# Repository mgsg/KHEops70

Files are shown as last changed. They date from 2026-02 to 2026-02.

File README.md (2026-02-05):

# KHEops70 
Keyboard | Hall Effect | OrthoLinear | Programmable | Standard-sized

| WARNING: DIY project. Use at your own risk!

| Forked from the [Moonboard Keyboard](https://github.com/certainly1182/MoonBoard).

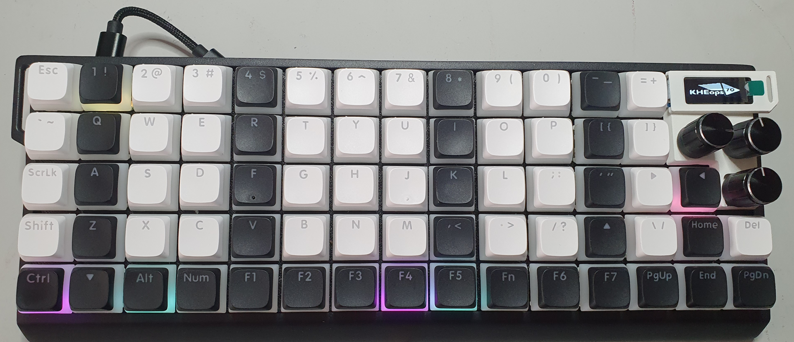
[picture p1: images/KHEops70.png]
KHEops70
<p>&nbsp;&nbsp;&nbsp;&nbsp;&nbsp;&nbsp;&nbsp;&nbsp;</p>

## Features

- 70 HE switches, 60% case, 13x5 + 5 keys + 1 encoder + 2 potentiometers in ortholinear arrangement.
- All keys are 1u. Keycaps in uniform profile preferred (XDA, DSA...).
- QMK Firmware compatibility.
- QMK MIDI Support (Audio support buggy).
- Compatibility with "standard" widely available 60% keyboard cases.
- OLED display.

## Hardware

Design for PCBs can be found in the hardware folder.

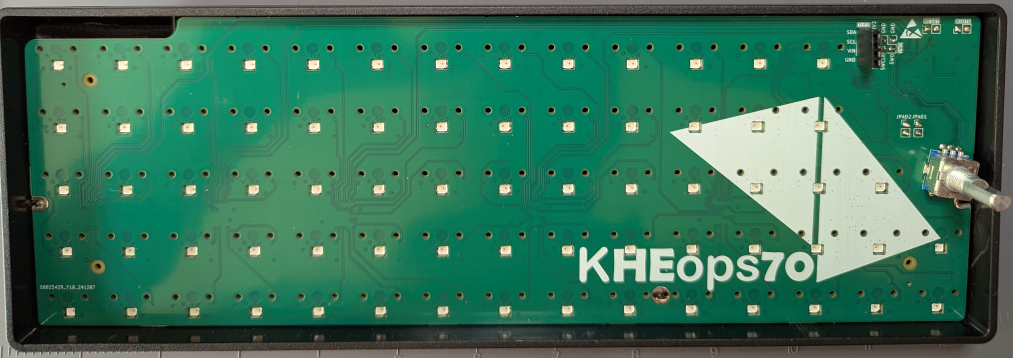
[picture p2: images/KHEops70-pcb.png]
KHEops70
<p>&nbsp;&nbsp;&nbsp;&nbsp;&nbsp;&nbsp;&nbsp;&nbsp;</p>

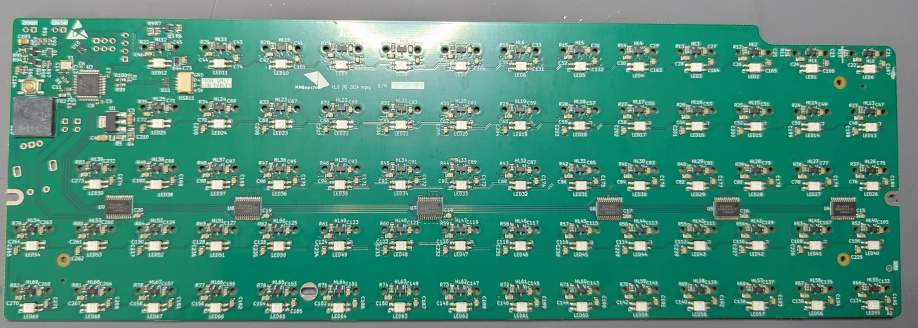
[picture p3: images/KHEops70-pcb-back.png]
KHEops70
<p>&nbsp;&nbsp;&nbsp;&nbsp;&nbsp;&nbsp;&nbsp;&nbsp;</p>

## Firmware

Compiled firmware provided as is. Largely based on the [Moonboard firmware found here](https://github.com/RephlexZero/qmk_firmware/tree/adc_testing/keyboards/rephlex/moonboard). Modified keyboard.json provided.

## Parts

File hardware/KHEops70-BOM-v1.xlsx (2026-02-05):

Comment | Designator | Footprint | JLCPCB Part #（optional）
r95 | BZ1 | Buzzer_Beeper:Buzzer_Murata_PKLCS1212E
PAD 1 Header | JPAD1 | Connector_PinHeader_2.54mm:PinHeader_1x02_P2.54mm_Vertical
PAD 2 Header | JPAD2 | Connector_PinHeader_2.54mm:PinHeader_1x02_P2.54mm_Vertical
RGB_DATA_OUT | TP1 | TestPoint:TestPoint_Pad_D1.5mm
STM32F303CBTx | U3 | Package_QFP:LQFP-48_7x7mm_P0.5mm | C108516
10u | C3 | Capacitor_SMD:C_1206_3216Metric | C13585
10u | C183 | Capacitor_SMD:C_1206_3216Metric | C13585
100u | C4 | Capacitor_SMD:C_1206_3216Metric | C15008
100n | C6 | Capacitor_SMD:C_0402_1005Metric | C1525
100n | C7 | Capacitor_SMD:C_0402_1005Metric | C1525
100n | C8 | Capacitor_SMD:C_0402_1005Metric | C1525
100n | C9 | Capacitor_SMD:C_0402_1005Metric | C1525
SM04B-SRSS-TB | USB11 | Connector_JST:JST_SH_SM04B-SRSS-TB_1x04-1MP_P1.00mm_Horizontal | C160404
10k | R93 | Resistor_SMD:R_0603_1608Metric | C17414
10k | R98 | Resistor_SMD:R_0603_1608Metric | C17414
10k | R6 | Resistor_SMD:R_0805_2012Metric | C17414
10k | R10 | Resistor_SMD:R_0805_2012Metric | C17414
10k | R11 | Resistor_SMD:R_0805_2012Metric | C17414
10k | R12 | Resistor_SMD:R_0805_2012Metric | C17414
10k | R13 | Resistor_SMD:R_0805_2012Metric | C17414
10k | R14 | Resistor_SMD:R_0805_2012Metric | C17414
10k | R15 | Resistor_SMD:R_0805_2012Metric | C17414
10k | R16 | Resistor_SMD:R_0805_2012Metric | C17414
10k | R17 | Resistor_SMD:R_0805_2012Metric | C17414
10k | R18 | Resistor_SMD:R_0805_2012Metric | C17414
10k | R19 | Resistor_SMD:R_0805_2012Metric | C17414
10k | R20 | Resistor_SMD:R_0805_2012Metric | C17414
10k | R21 | Resistor_SMD:R_0805_2012Metric | C17414
10k | R22 | Resistor_SMD:R_0805_2012Metric | C17414
10k | R23 | Resistor_SMD:R_0805_2012Metric | C17414
10k | R24 | Resistor_SMD:R_0805_2012Metric | C17414
10k | R25 | Resistor_SMD:R_0805_2012Metric | C17414
10k | R26 | Resistor_SMD:R_0805_2012Metric | C17414
10k | R27 | Resistor_SMD:R_0805_2012Metric | C17414
10k | R28 | Resistor_SMD:R_0805_2012Metric | C17414
10k | R29 | Resistor_SMD:R_0805_2012Metric | C17414
10k | R30 | Resistor_SMD:R_0805_2012Metric | C17414
10k | R31 | Resistor_SMD:R_0805_2012Metric | C17414
10k | R32 | Resistor_SMD:R_0805_2012Metric | C17414
10k | R33 | Resistor_SMD:R_0805_2012Metric | C17414
10k | R34 | Resistor_SMD:R_0805_2012Metric | C17414
10k | R35 | Resistor_SMD:R_0805_2012Metric | C17414
10k | R37 | Resistor_SMD:R_0805_2012Metric | C17414
10k | R38 | Resistor_SMD:R_0805_2012Metric | C17414
10k | R39 | Resistor_SMD:R_0805_2012Metric | C17414
10k | R40 | Resistor_SMD:R_0805_2012Metric | C17414
10k | R41 | Resistor_SMD:R_0805_2012Metric | C17414
10k | R42 | Resistor_SMD:R_0805_2012Metric | C17414
10k | R43 | Resistor_SMD:R_0805_2012Metric | C17414
10k | R44 | Resistor_SMD:R_0805_2012Metric | C17414
10k | R45 | Resistor_SMD:R_0805_2012Metric | C17414
10k | R46 | Resistor_SMD:R_0805_2012Metric | C17414
10k | R47 | Resistor_SMD:R_0805_2012Metric | C17414
10k | R48 | Resistor_SMD:R_0805_2012Metric | C17414
10k | R49 | Resistor_SMD:R_0805_2012Metric | C17414
10k | R52 | Resistor_SMD:R_0805_2012Metric | C17414
10k | R53 | Resistor_SMD:R_0805_2012Metric | C17414
10k | R54 | Resistor_SMD:R_0805_2012Metric | C17414
10k | R55 | Resistor_SMD:R_0805_2012Metric | C17414
10k | R56 | Resistor_SMD:R_0805_2012Metric | C17414
10k | R57 | Resistor_SMD:R_0805_2012Metric | C17414
10k | R58 | Resistor_SMD:R_0805_2012Metric | C17414
10k | R59 | Resistor_SMD:R_0805_2012Metric | C17414
10k | R60 | Resistor_SMD:R_0805_2012Metric | C17414
10k | R61 | Resistor_SMD:R_0805_2012Metric | C17414
10k | R62 | Resistor_SMD:R_0805_2012Metric | C17414
10k | R63 | Resistor_SMD:R_0805_2012Metric | C17414
10k | R64 | Resistor_SMD:R_0805_2012Metric | C17414
10k | R66 | Resistor_SMD:R_0805_2012Metric | C17414
10k | R67 | Resistor_SMD:R_0805_2012Metric | C17414
10k | R68 | Resistor_SMD:R_0805_2012Metric | C17414
10k | R69 | Resistor_SMD:R_0805_2012Metric | C17414
10k | R70 | Resistor_SMD:R_0805_2012Metric | C17414
10k | R71 | Resistor_SMD:R_0805_2012Metric | C17414
10k | R72 | Resistor_SMD:R_0805_2012Metric | C17414
10k | R73 | Resistor_SMD:R_0805_2012Metric | C17414
10k | R74 | Resistor_SMD:R_0805_2012Metric | C17414
10k | R75 | Resistor_SMD:R_0805_2012Metric | C17414
10k | R76 | Resistor_SMD:R_0805_2012Metric | C17414
10k | R77 | Resistor_SMD:R_0805_2012Metric | C17414
10k | R78 | Resistor_SMD:R_0805_2012Metric | C17414
10k | R79 | Resistor_SMD:R_0805_2012Metric | C17414
10k | R80 | Resistor_SMD:R_0805_2012Metric | C17414
10k | R81 | Resistor_SMD:R_0805_2012Metric | C17414
10k | R82 | Resistor_SMD:R_0805_2012Metric | C17414
10k | R83 | Resistor_SMD:R_0805_2012Metric | C17414
10k | R94 | Resistor_SMD:R_0805_2012Metric | C17414
1k | R7 | Resistor_SMD:R_0805_2012Metric | C17513
1 | R4 | Resistor_SMD:R_1206_3216Metric | C17928
1 | R5 | Resistor_SMD:R_1206_3216Metric | C17928
74HC4067 | U4 | Package_SO:TSSOP-24_4.4x7.8mm_P0.65mm | C179326
74HC4067 | U5 | Package_SO:TSSOP-24_4.4x7.8mm_P0.65mm | C179326
74HC4067 | U6 | Package_SO:TSSOP-24_4.4x7.8mm_P0.65mm | C179326
74HC4067 | U7 | Package_SO:TSSOP-24_4.4x7.8mm_P0.65mm | C179326
74HC4067 | U8 | Package_SO:TSSOP-24_4.4x7.8mm_P0.65mm | C179326
74HC4067 | U9 | Package_SO:TSSOP-24_4.4x7.8mm_P0.65mm | C179326
H5VU25U | U10 | MoonBoard:DFN2510 | C20615800
H5VU25U | U11 | MoonBoard:DFN2510 | C20615800
0 | R8 | Resistor_SMD:R_0603_1608Metric_Pad0.98x0.95mm_HandSolder | C21189
0 | R99 | Resistor_SMD:R_0603_1608Metric_Pad0.98x0.95mm_HandSolder | C21189
0 | R100 | Resistor_SMD:R_0603_1608Metric_Pad0.98x0.95mm_HandSolder | C21189
1k | R97 | Resistor_SMD:R_0603_1608Metric | C21190
1N4148WS | D1 | Diode_SMD:D_SOD-323 | C2128
1N4148WS | D44 | Diode_SMD:D_SOD-323 | C2128
1M | R92 | Resistor_SMD:R_0603_1608Metric | C22935
330k | R91 | Resistor_SMD:R_0603_1608Metric | C23137
4u7 | C5 | Capacitor_SMD:C_0402_1005Metric | C23733
100 | R96 | Resistor_SMD:R_0805_2012Metric | C25076
470R | R2 | Resistor_SMD:R_0805_2012Metric | C25117
470 | R9 | Resistor_SMD:R_0805_2012Metric | C25117
100k | R95 | Resistor_SMD:R_0805_2012Metric | C25741
1k5 | R1 | Resistor_SMD:R_0805_2012Metric | C25867
SW_SPST | SW1 | Button_Switch_SMD:SW_SPST_TL3342 | C2886897
SLSS49E-3 | HL0 | MoonBoard:SLSS49E-3 with MX holes | C2904393
SLSS49E-3 | HL1 | MoonBoard:SLSS49E-3 with MX holes | C2904393
SLSS49E-3 | HL2 | MoonBoard:SLSS49E-3 with MX holes | C2904393
SLSS49E-3 | HL3 | MoonBoard:SLSS49E-3 with MX holes | C2904393
SLSS49E-3 | HL4 | MoonBoard:SLSS49E-3 with MX holes | C2904393
SLSS49E-3 | HL5 | MoonBoard:SLSS49E-3 with MX holes | C2904393
SLSS49E-3 | HL6 | MoonBoard:SLSS49E-3 with MX holes | C2904393
SLSS49E-3 | HL7 | MoonBoard:SLSS49E-3 with MX holes | C2904393
SLSS49E-3 | HL8 | MoonBoard:SLSS49E-3 with MX holes | C2904393
SLSS49E-3 | HL9 | MoonBoard:SLSS49E-3 with MX holes | C2904393
SLSS49E-3 | HL10 | MoonBoard:SLSS49E-3 with MX holes | C2904393
SLSS49E-3 | HL11 | MoonBoard:SLSS49E-3 with MX holes | C2904393
SLSS49E-3 | HL12 | MoonBoard:SLSS49E-3 with MX holes | C2904393
SLSS49E-3 | HL13 | MoonBoard:SLSS49E-3 with MX holes | C2904393
SLSS49E-3 | HL14 | MoonBoard:SLSS49E-3 with MX holes | C2904393
SLSS49E-3 | HL15 | MoonBoard:SLSS49E-3 with MX holes | C2904393
SLSS49E-3 | HL16 | MoonBoard:SLSS49E-3 with MX holes | C2904393
SLSS49E-3 | HL17 | MoonBoard:SLSS49E-3 with MX holes | C2904393
SLSS49E-3 | HL18 | MoonBoard:SLSS49E-3 with MX holes | C2904393
SLSS49E-3 | HL19 | MoonBoard:SLSS49E-3 with MX holes | C2904393
SLSS49E-3 | HL20 | MoonBoard:SLSS49E-3 with MX holes | C2904393
SLSS49E-3 | HL21 | MoonBoard:SLSS49E-3 with MX holes | C2904393
SLSS49E-3 | HL22 | MoonBoard:SLSS49E-3 with MX holes | C2904393
SLSS49E-3 | HL23 | MoonBoard:SLSS49E-3 with MX holes | C2904393
SLSS49E-3 | HL24 | MoonBoard:SLSS49E-3 with MX holes | C2904393
SLSS49E-3 | HL25 | MoonBoard:SLSS49E-3 with MX holes | C2904393
SLSS49E-3 | HL26 | MoonBoard:SLSS49E-3 with MX holes | C2904393
SLSS49E-3 | HL27 | MoonBoard:SLSS49E-3 with MX holes | C2904393
SLSS49E-3 | HL28 | MoonBoard:SLSS49E-3 with MX holes | C2904393
SLSS49E-3 | HL29 | MoonBoard:SLSS49E-3 with MX holes | C2904393
SLSS49E-3 | HL30 | MoonBoard:SLSS49E-3 with MX holes | C2904393
SLSS49E-3 | HL31 | MoonBoard:SLSS49E-3 with MX holes | C2904393
SLSS49E-3 | HL32 | MoonBoard:SLSS49E-3 with MX holes | C2904393
SLSS49E-3 | HL33 | MoonBoard:SLSS49E-3 with MX holes | C2904393
SLSS49E-3 | HL34 | MoonBoard:SLSS49E-3 with MX holes | C2904393
SLSS49E-3 | HL35 | MoonBoard:SLSS49E-3 with MX holes | C2904393
SLSS49E-3 | HL36 | MoonBoard:SLSS49E-3 with MX holes | C2904393
SLSS49E-3 | HL37 | MoonBoard:SLSS49E-3 with MX holes | C2904393
SLSS49E-3 | HL38 | MoonBoard:SLSS49E-3 with MX holes | C2904393
SLSS49E-3 | HL39 | MoonBoard:SLSS49E-3 with MX holes | C2904393
SLSS49E-3 | HL40 | MoonBoard:SLSS49E-3 with MX holes | C2904393
SLSS49E-3 | HL41 | MoonBoard:SLSS49E-3 with MX holes | C2904393
SLSS49E-3 | HL42 | MoonBoard:SLSS49E-3 with MX holes | C2904393
SLSS49E-3 | HL43 | MoonBoard:SLSS49E-3 with MX holes | C2904393
SLSS49E-3 | HL44 | MoonBoard:SLSS49E-3 with MX holes | C2904393
SLSS49E-3 | HL45 | MoonBoard:SLSS49E-3 with MX holes | C2904393
SLSS49E-3 | HL46 | MoonBoard:SLSS49E-3 with MX holes | C2904393
SLSS49E-3 | HL47 | MoonBoard:SLSS49E-3 with MX holes | C2904393
SLSS49E-3 | HL48 | MoonBoard:SLSS49E-3 with MX holes | C2904393
SLSS49E-3 | HL49 | MoonBoard:SLSS49E-3 with MX holes | C2904393
SLSS49E-3 | HL50 | MoonBoard:SLSS49E-3 with MX holes | C2904393
SLSS49E-3 | HL51 | MoonBoard:SLSS49E-3 with MX holes | C2904393
SLSS49E-3 | HL52 | MoonBoard:SLSS49E-3 with MX holes | C2904393
SLSS49E-3 | HL53 | MoonBoard:SLSS49E-3 with MX holes | C2904393
SLSS49E-3 | HL54 | MoonBoard:SLSS49E-3 with MX holes | C2904393
SLSS49E-3 | HL55 | MoonBoard:SLSS49E-3 with MX holes | C2904393
SLSS49E-3 | HL56 | MoonBoard:SLSS49E-3 with MX holes | C2904393
SLSS49E-3 | HL57 | MoonBoard:SLSS49E-3 with MX holes | C2904393
SLSS49E-3 | HL58 | MoonBoard:SLSS49E-3 with MX holes | C2904393
SLSS49E-3 | HL59 | MoonBoard:SLSS49E-3 with MX holes | C2904393
SLSS49E-3 | HL60 | MoonBoard:SLSS49E-3 with MX holes | C2904393
SLSS49E-3 | HL61 | MoonBoard:SLSS49E-3 with MX holes | C2904393
SLSS49E-3 | HL62 | MoonBoard:SLSS49E-3 with MX holes | C2904393
SLSS49E-3 | HL63 | MoonBoard:SLSS49E-3 with MX holes | C2904393
SLSS49E-3 | HL64 | MoonBoard:SLSS49E-3 with MX holes | C2904393
SLSS49E-3 | HL65 | MoonBoard:SLSS49E-3 with MX holes | C2904393
SLSS49E-3 | HL66 | MoonBoard:SLSS49E-3 with MX holes | C2904393
SLSS49E-3 | HL67 | MoonBoard:SLSS49E-3 with MX holes | C2904393
SLSS49E-3 | HL68 | MoonBoard:SLSS49E-3 with MX holes | C2904393
SLSS49E-3 | HL69 | MoonBoard:SLSS49E-3 with MX holes | C2904393
1u | C10 | Capacitor_SMD:C_0402_1005Metric | C29266
1u | C11 | Capacitor_SMD:C_0402_1005Metric | C29266
10p | C13 | Capacitor_SMD:C_0402_1005Metric | C32949
10p | C14 | Capacitor_SMD:C_0402_1005Metric | C32949
100n | C15 | Capacitor_SMD:C_0805_2012Metric | C49678
100n | C16 | Capacitor_SMD:C_0805_2012Metric | C49678
100n | C17 | Capacitor_SMD:C_0805_2012Metric | C49678
100n | C18 | Capacitor_SMD:C_0805_2012Metric | C49678
100n | C19 | Capacitor_SMD:C_0805_2012Metric | C49678
100n | C20 | Capacitor_SMD:C_0805_2012Metric | C49678
100n | C21 | Capacitor_SMD:C_0805_2012Metric | C49678
100n | C22 | Capacitor_SMD:C_0805_2012Metric | C49678
100n | C23 | Capacitor_SMD:C_0805_2012Metric | C49678
100n | C24 | Capacitor_SMD:C_0805_2012Metric | C49678
100n | C25 | Capacitor_SMD:C_0805_2012Metric | C49678
100n | C26 | Capacitor_SMD:C_0805_2012Metric | C49678
100n | C27 | Capacitor_SMD:C_0805_2012Metric | C49678
100n | C28 | Capacitor_SMD:C_0805_2012Metric | C49678
100n | C29 | Capacitor_SMD:C_0805_2012Metric | C49678
100n | C30 | Capacitor_SMD:C_0805_2012Metric | C49678
100n | C31 | Capacitor_SMD:C_0805_2012Metric | C49678
100n | C32 | Capacitor_SMD:C_0805_2012Metric | C49678
100n | C33 | Capacitor_SMD:C_0805_2012Metric | C49678
100n | C34 | Capacitor_SMD:C_0805_2012Metric | C49678
100n | C35 | Capacitor_SMD:C_0805_2012Metric | C49678
100n | C36 | Capacitor_SMD:C_0805_2012Metric | C49678
100n | C37 | Capacitor_SMD:C_0805_2012Metric | C49678
100n | C38 | Capacitor_SMD:C_0805_2012Metric | C49678
100n | C39 | Capacitor_SMD:C_0805_2012Metric | C49678
100n | C40 | Capacitor_SMD:C_0805_2012Metric | C49678
100n | C41 | Capacitor_SMD:C_0805_2012Metric | C49678
100n | C42 | Capacitor_SMD:C_0805_2012Metric | C49678
100n | C43 | Capacitor_SMD:C_0805_2012Metric | C49678
100n | C44 | Capacitor_SMD:C_0805_2012Metric | C49678
100n | C45 | Capacitor_SMD:C_0805_2012Metric | C49678
100n | C46 | Capacitor_SMD:C_0805_2012Metric | C49678
100n | C47 | Capacitor_SMD:C_0805_2012Metric | C49678
100n | C48 | Capacitor_SMD:C_0805_2012Metric | C49678
100n | C49 | Capacitor_SMD:C_0805_2012Metric | C49678
100n | C50 | Capacitor_SMD:C_0805_2012Metric | C49678
100n | C51 | Capacitor_SMD:C_0805_2012Metric | C49678
100n | C52 | Capacitor_SMD:C_0805_2012Metric | C49678
100n | C53 | Capacitor_SMD:C_0805_2012Metric | C49678
100n | C54 | Capacitor_SMD:C_0805_2012Metric | C49678
100n | C55 | Capacitor_SMD:C_0805_2012Metric | C49678
100n | C56 | Capacitor_SMD:C_0805_2012Metric | C49678
100n | C57 | Capacitor_SMD:C_0805_2012Metric | C49678
100n | C58 | Capacitor_SMD:C_0805_2012Metric | C49678
100n | C59 | Capacitor_SMD:C_0805_2012Metric | C49678
100n | C60 | Capacitor_SMD:C_0805_2012Metric | C49678
100n | C61 | Capacitor_SMD:C_0805_2012Metric | C49678
100n | C62 | Capacitor_SMD:C_0805_2012Metric | C49678
100n | C63 | Capacitor_SMD:C_0805_2012Metric | C49678
100n | C64 | Capacitor_SMD:C_0805_2012Metric | C49678
100n | C65 | Capacitor_SMD:C_0805_2012Metric | C49678
100n | C66 | Capacitor_SMD:C_0805_2012Metric | C49678
100n | C67 | Capacitor_SMD:C_0805_2012Metric | C49678
100n | C68 | Capacitor_SMD:C_0805_2012Metric | C49678
100n | C69 | Capacitor_SMD:C_0805_2012Metric | C49678
100n | C70 | Capacitor_SMD:C_0805_2012Metric | C49678
100n | C71 | Capacitor_SMD:C_0805_2012Metric | C49678
100n | C72 | Capacitor_SMD:C_0805_2012Metric | C49678
100n | C73 | Capacitor_SMD:C_0805_2012Metric | C49678
100n | C74 | Capacitor_SMD:C_0805_2012Metric | C49678
100n | C75 | Capacitor_SMD:C_0805_2012Metric | C49678
100n | C76 | Capacitor_SMD:C_0805_2012Metric | C49678
100n | C77 | Capacitor_SMD:C_0805_2012Metric | C49678
100n | C78 | Capacitor_SMD:C_0805_2012Metric | C49678
100n | C79 | Capacitor_SMD:C_0805_2012Metric | C49678
100n | C80 | Capacitor_SMD:C_0805_2012Metric | C49678
100n | C81 | Capacitor_SMD:C_0805_2012Metric | C49678
100n | C82 | Capacitor_SMD:C_0805_2012Metric | C49678
100n | C83 | Capacitor_SMD:C_0805_2012Metric | C49678
100n | C84 | Capacitor_SMD:C_0805_2012Metric | C49678
100n | C85 | Capacitor_SMD:C_0805_2012Metric | C49678
100n | C86 | Capacitor_SMD:C_0805_2012Metric | C49678
100n | C87 | Capacitor_SMD:C_0805_2012Metric | C49678
100n | C88 | Capacitor_SMD:C_0805_2012Metric | C49678
100n | C89 | Capacitor_SMD:C_0805_2012Metric | C49678
100n | C90 | Capacitor_SMD:C_0805_2012Metric | C49678
100n | C91 | Capacitor_SMD:C_0805_2012Metric | C49678
100n | C92 | Capacitor_SMD:C_0805_2012Metric | C49678
100n | C93 | Capacitor_SMD:C_0805_2012Metric | C49678
100n | C94 | Capacitor_SMD:C_0805_2012Metric | C49678
100n | C95 | Capacitor_SMD:C_0805_2012Metric | C49678
100n | C96 | Capacitor_SMD:C_0805_2012Metric | C49678
100n | C97 | Capacitor_SMD:C_0805_2012Metric | C49678
100n | C98 | Capacitor_SMD:C_0805_2012Metric | C49678
100n | C99 | Capacitor_SMD:C_0805_2012Metric | C49678
100n | C100 | Capacitor_SMD:C_0805_2012Metric | C49678
100n | C101 | Capacitor_SMD:C_0805_2012Metric | C49678
100n | C102 | Capacitor_SMD:C_0805_2012Metric | C49678
100n | C103 | Capacitor_SMD:C_0805_2012Metric | C49678
100n | C104 | Capacitor_SMD:C_0805_2012Metric | C49678
100n | C105 | Capacitor_SMD:C_0805_2012Metric | C49678
100n | C106 | Capacitor_SMD:C_0805_2012Metric | C49678
100n | C107 | Capacitor_SMD:C_0805_2012Metric | C49678
100n | C108 | Capacitor_SMD:C_0805_2012Metric | C49678
100n | C109 | Capacitor_SMD:C_0805_2012Metric | C49678
100n | C110 | Capacitor_SMD:C_0805_2012Metric | C49678
100n | C111 | Capacitor_SMD:C_0805_2012Metric | C49678
100n | C112 | Capacitor_SMD:C_0805_2012Metric | C49678
100n | C113 | Capacitor_SMD:C_0805_2012Metric | C49678
100n | C114 | Capacitor_SMD:C_0805_2012Metric | C49678
100n | C115 | Capacitor_SMD:C_0805_2012Metric | C49678
100n | C116 | Capacitor_SMD:C_0805_2012Metric | C49678
100n | C117 | Capacitor_SMD:C_0805_2012Metric | C49678
100n | C118 | Capacitor_SMD:C_0805_2012Metric | C49678
100n | C119 | Capacitor_SMD:C_0805_2012Metric | C49678
100n | C120 | Capacitor_SMD:C_0805_2012Metric | C49678
100n | C121 | Capacitor_SMD:C_0805_2012Metric | C49678
100n | C122 | Capacitor_SMD:C_0805_2012Metric | C49678
100n | C123 | Capacitor_SMD:C_0805_2012Metric | C49678
100n | C124 | Capacitor_SMD:C_0805_2012Metric | C49678
100n | C125 | Capacitor_SMD:C_0805_2012Metric | C49678
100n | C126 | Capacitor_SMD:C_0805_2012Metric | C49678
100n | C127 | Capacitor_SMD:C_0805_2012Metric | C49678
100n | C128 | Capacitor_SMD:C_0805_2012Metric | C49678
100n | C129 | Capacitor_SMD:C_0805_2012Metric | C49678
100n | C130 | Capacitor_SMD:C_0805_2012Metric | C49678
100n | C131 | Capacitor_SMD:C_0805_2012Metric | C49678
100n | C132 | Capacitor_SMD:C_0805_2012Metric | C49678
100n | C133 | Capacitor_SMD:C_0805_2012Metric | C49678
100n | C134 | Capacitor_SMD:C_0805_2012Metric | C49678
100n | C135 | Capacitor_SMD:C_0805_2012Metric | C49678
100n | C136 | Capacitor_SMD:C_0805_2012Metric | C49678
100n | C137 | Capacitor_SMD:C_0805_2012Metric | C49678
100n | C138 | Capacitor_SMD:C_0805_2012Metric | C49678
100n | C139 | Capacitor_SMD:C_0805_2012Metric | C49678
100n | C140 | Capacitor_SMD:C_0805_2012Metric | C49678
100n | C141 | Capacitor_SMD:C_0805_2012Metric | C49678
100n | C142 | Capacitor_SMD:C_0805_2012Metric | C49678
100n | C143 | Capacitor_SMD:C_0805_2012Metric | C49678
100n | C144 | Capacitor_SMD:C_0805_2012Metric | C49678
100n | C145 | Capacitor_SMD:C_0805_2012Metric | C49678
100n | C146 | Capacitor_SMD:C_0805_2012Metric | C49678
100n | C147 | Capacitor_SMD:C_0805_2012Metric | C49678
100n | C148 | Capacitor_SMD:C_0805_2012Metric | C49678
100n | C149 | Capacitor_SMD:C_0805_2012Metric | C49678
100n | C150 | Capacitor_SMD:C_0805_2012Metric | C49678
100n | C151 | Capacitor_SMD:C_0805_2012Metric | C49678
100n | C152 | Capacitor_SMD:C_0805_2012Metric | C49678
100n | C153 | Capacitor_SMD:C_0805_2012Metric | C49678
100n | C154 | Capacitor_SMD:C_0805_2012Metric | C49678
100n | C155 | Capacitor_SMD:C_0805_2012Metric | C49678
100n | C156 | Capacitor_SMD:C_0805_2012Metric | C49678
100n | C157 | Capacitor_SMD:C_0805_2012Metric | C49678
100n | C158 | Capacitor_SMD:C_0805_2012Metric | C49678
100n | C163 | Capacitor_SMD:C_0805_2012Metric | C49678
100n | C164 | Capacitor_SMD:C_0805_2012Metric | C49678
100n | C165 | Capacitor_SMD:C_0805_2012Metric | C49678
100n | C166 | Capacitor_SMD:C_0805_2012Metric | C49678
100n | C167 | Capacitor_SMD:C_0805_2012Metric | C49678
100n | C168 | Capacitor_SMD:C_0805_2012Metric | C49678
100n | C169 | Capacitor_SMD:C_0805_2012Metric | C49678
100n | C170 | Capacitor_SMD:C_0805_2012Metric | C49678
100n | C171 | Capacitor_SMD:C_0805_2012Metric | C49678
100n | C172 | Capacitor_SMD:C_0805_2012Metric | C49678
100n | C173 | Capacitor_SMD:C_0805_2012Metric | C49678
100n | C174 | Capacitor_SMD:C_0805_2012Metric | C49678
100n | C175 | Capacitor_SMD:C_0805_2012Metric | C49678
100n | C176 | Capacitor_SMD:C_0805_2012Metric | C49678
100n | C177 | Capacitor_SMD:C_0805_2012Metric | C49678
100n | C178 | Capacitor_SMD:C_0805_2012Metric | C49678
100n | C179 | Capacitor_SMD:C_0805_2012Metric | C49678
100n | C180 | Capacitor_SMD:C_0805_2012Metric | C49678
100n | C181 | Capacitor_SMD:C_0805_2012Metric | C49678
100n | C182 | Capacitor_SMD:C_0805_2012Metric | C49678
100n | C184 | Capacitor_SMD:C_0805_2012Metric | C49678
100n | C185 | Capacitor_SMD:C_0805_2012Metric | C49678
100n | C186 | Capacitor_SMD:C_0805_2012Metric | C49678
100n | C187 | Capacitor_SMD:C_0805_2012Metric | C49678
100n | C188 | Capacitor_SMD:C_0805_2012Metric | C49678
100n | C189 | Capacitor_SMD:C_0805_2012Metric | C49678
100n | C190 | Capacitor_SMD:C_0805_2012Metric | C49678
100n | C191 | Capacitor_SMD:C_0805_2012Metric | C49678
100n | C192 | Capacitor_SMD:C_0805_2012Metric | C49678
100n | C193 | Capacitor_SMD:C_0805_2012Metric | C49678
100n | C194 | Capacitor_SMD:C_0805_2012Metric | C49678
100n | C195 | Capacitor_SMD:C_0805_2012Metric | C49678
100n | C198 | Capacitor_SMD:C_0805_2012Metric | C49678
100n | C199 | Capacitor_SMD:C_0805_2012Metric | C49678
100n | C200 | Capacitor_SMD:C_0805_2012Metric | C49678
100n | C201 | Capacitor_SMD:C_0805_2012Metric | C49678
100n | C202 | Capacitor_SMD:C_0805_2012Metric | C49678
100n | C203 | Capacitor_SMD:C_0805_2012Metric | C49678
100n | C204 | Capacitor_SMD:C_0805_2012Metric | C49678
100n | C205 | Capacitor_SMD:C_0805_2012Metric | C49678
100n | C206 | Capacitor_SMD:C_0805_2012Metric | C49678
100n | C207 | Capacitor_SMD:C_0805_2012Metric | C49678
100n | C208 | Capacitor_SMD:C_0805_2012Metric | C49678
100n | C209 | Capacitor_SMD:C_0805_2012Metric | C49678
100n | C210 | Capacitor_SMD:C_0805_2012Metric | C49678
100n | C225 | Capacitor_SMD:C_0805_2012Metric | C49678
100n | C226 | Capacitor_SMD:C_0805_2012Metric | C49678
100n | C227 | Capacitor_SMD:C_0805_2012Metric | C49678
100n | C228 | Capacitor_SMD:C_0805_2012Metric | C49678
100n | C229 | Capacitor_SMD:C_0805_2012Metric | C49678
100n | C230 | Capacitor_SMD:C_0805_2012Metric | C49678
100n | C231 | Capacitor_SMD:C_0805_2012Metric | C49678
100n | C232 | Capacitor_SMD:C_0805_2012Metric | C49678
100n | C233 | Capacitor_SMD:C_0805_2012Metric | C49678
100n | C234 | Capacitor_SMD:C_0805_2012Metric | C49678
100n | C235 | Capacitor_SMD:C_0805_2012Metric | C49678
100n | C236 | Capacitor_SMD:C_0805_2012Metric | C49678
100n | C237 | Capacitor_SMD:C_0805_2012Metric | C49678
100n | C260 | Capacitor_SMD:C_0805_2012Metric | C49678
100n | C261 | Capacitor_SMD:C_0805_2012Metric | C49678
100n | C262 | Capacitor_SMD:C_0805_2012Metric | C49678
100n | C263 | Capacitor_SMD:C_0805_2012Metric | C49678
100n | C264 | Capacitor_SMD:C_0805_2012Metric | C49678
100n | C265 | Capacitor_SMD:C_0805_2012Metric | C49678
100n | C266 | Capacitor_SMD:C_0805_2012Metric | C49678
100n | C267 | Capacitor_SMD:C_0805_2012Metric | C49678
100n | C268 | Capacitor_SMD:C_0805_2012Metric | C49678
100n | C269 | Capacitor_SMD:C_0805_2012Metric | C49678
100n | C270 | Capacitor_SMD:C_0805_2012Metric | C49678
100n | C271 | Capacitor_SMD:C_0805_2012Metric | C49678
100n | C272 | Capacitor_SMD:C_0805_2012Metric | C49678
100n | C273 | Capacitor_SMD:C_0805_2012Metric | C49678
100n | C274 | Capacitor_SMD:C_0805_2012Metric | C49678
8MHz | Y1 | Crystal:Crystal_SMD_3225-4Pin_3.2x2.5mm | C518154
BSS138 | Q1 | Package_TO_SOT_SMD:SOT-23 | C5224263
BSS138 | Q2 | Package_TO_SOT_SMD:SOT-23 | C5224263
BSS138 | Q3 | Package_TO_SOT_SMD:SOT-23 | C5224263
MX_SK6812MINI-EA | LED13 | KHEops70:SK 6812 MINI-EA-ROT | C5378731
MX_SK6812MINI-EA | LED14 | KHEops70:SK 6812 MINI-EA-ROT | C5378731
MX_SK6812MINI-EA | LED15 | KHEops70:SK 6812 MINI-EA-ROT | C5378731
MX_SK6812MINI-EA | LED16 | KHEops70:SK 6812 MINI-EA-ROT | C5378731
MX_SK6812MINI-EA | LED17 | KHEops70:SK 6812 MINI-EA-ROT | C5378731
MX_SK6812MINI-EA | LED18 | KHEops70:SK 6812 MINI-EA-ROT | C5378731
MX_SK6812MINI-EA | LED19 | KHEops70:SK 6812 MINI-EA-ROT | C5378731
MX_SK6812MINI-EA | LED20 | KHEops70:SK 6812 MINI-EA-ROT | C5378731
MX_SK6812MINI-EA | LED21 | KHEops70:SK 6812 MINI-EA-ROT | C5378731
MX_SK6812MINI-EA | LED22 | KHEops70:SK 6812 MINI-EA-ROT | C5378731
MX_SK6812MINI-EA | LED23 | KHEops70:SK 6812 MINI-EA-ROT | C5378731
MX_SK6812MINI-EA | LED24 | KHEops70:SK 6812 MINI-EA-ROT | C5378731
MX_SK6812MINI-EA | LED25 | KHEops70:SK 6812 MINI-EA-ROT | C5378731
MX_SK6812MINI-EA | LED40 | KHEops70:SK 6812 MINI-EA-ROT | C5378731
MX_SK6812MINI-EA | LED41 | KHEops70:SK 6812 MINI-EA-ROT | C5378731
MX_SK6812MINI-EA | LED42 | KHEops70:SK 6812 MINI-EA-ROT | C5378731
MX_SK6812MINI-EA | LED43 | KHEops70:SK 6812 MINI-EA-ROT | C5378731
MX_SK6812MINI-EA | LED44 | KHEops70:SK 6812 MINI-EA-ROT | C5378731
MX_SK6812MINI-EA | LED45 | KHEops70:SK 6812 MINI-EA-ROT | C5378731
MX_SK6812MINI-EA | LED46 | KHEops70:SK 6812 MINI-EA-ROT | C5378731
MX_SK6812MINI-EA | LED47 | KHEops70:SK 6812 MINI-EA-ROT | C5378731
MX_SK6812MINI-EA | LED48 | KHEops70:SK 6812 MINI-EA-ROT | C5378731
MX_SK6812MINI-EA | LED49 | KHEops70:SK 6812 MINI-EA-ROT | C5378731
MX_SK6812MINI-EA | LED50 | KHEops70:SK 6812 MINI-EA-ROT | C5378731
MX_SK6812MINI-EA | LED51 | KHEops70:SK 6812 MINI-EA-ROT | C5378731
MX_SK6812MINI-EA | LED52 | KHEops70:SK 6812 MINI-EA-ROT | C5378731
MX_SK6812MINI-EA | LED53 | KHEops70:SK 6812 MINI-EA-ROT | C5378731
MX_SK6812MINI-EA | LED54 | KHEops70:SK 6812 MINI-EA-ROT | C5378731
MX_SK6812MINI-EA | LED0 | MoonBoard:SK 6812 MINI-EA | C5378731
MX_SK6812MINI-EA | LED1 | MoonBoard:SK 6812 MINI-EA | C5378731
MX_SK6812MINI-EA | LED2 | MoonBoard:SK 6812 MINI-EA | C5378731
MX_SK6812MINI-EA | LED3 | MoonBoard:SK 6812 MINI-EA | C5378731
MX_SK6812MINI-EA | LED4 | MoonBoard:SK 6812 MINI-EA | C5378731
MX_SK6812MINI-EA | LED5 | MoonBoard:SK 6812 MINI-EA | C5378731
MX_SK6812MINI-EA | LED6 | MoonBoard:SK 6812 MINI-EA | C5378731
MX_SK6812MINI-EA | LED7 | MoonBoard:SK 6812 MINI-EA | C5378731
MX_SK6812MINI-EA | LED8 | MoonBoard:SK 6812 MINI-EA | C5378731
MX_SK6812MINI-EA | LED9 | MoonBoard:SK 6812 MINI-EA | C5378731
MX_SK6812MINI-EA | LED10 | MoonBoard:SK 6812 MINI-EA | C5378731
MX_SK6812MINI-EA | LED11 | MoonBoard:SK 6812 MINI-EA | C5378731
MX_SK6812MINI-EA | LED12 | MoonBoard:SK 6812 MINI-EA | C5378731
MX_SK6812MINI-EA | LED26 | MoonBoard:SK 6812 MINI-EA | C5378731
MX_SK6812MINI-EA | LED27 | MoonBoard:SK 6812 MINI-EA | C5378731
MX_SK6812MINI-EA | LED28 | MoonBoard:SK 6812 MINI-EA | C5378731
MX_SK6812MINI-EA | LED29 | MoonBoard:SK 6812 MINI-EA | C5378731
MX_SK6812MINI-EA | LED30 | MoonBoard:SK 6812 MINI-EA | C5378731
MX_SK6812MINI-EA | LED31 | MoonBoard:SK 6812 MINI-EA | C5378731
MX_SK6812MINI-EA | LED32 | MoonBoard:SK 6812 MINI-EA | C5378731
MX_SK6812MINI-EA | LED33 | MoonBoard:SK 6812 MINI-EA | C5378731
MX_SK6812MINI-EA | LED34 | MoonBoard:SK 6812 MINI-EA | C5378731
MX_SK6812MINI-EA | LED35 | MoonBoard:SK 6812 MINI-EA | C5378731
MX_SK6812MINI-EA | LED36 | MoonBoard:SK 6812 MINI-EA | C5378731
MX_SK6812MINI-EA | LED37 | MoonBoard:SK 6812 MINI-EA | C5378731
MX_SK6812MINI-EA | LED38 | MoonBoard:SK 6812 MINI-EA | C5378731
MX_SK6812MINI-EA | LED39 | MoonBoard:SK 6812 MINI-EA | C5378731
MX_SK6812MINI-EA | LED55 | MoonBoard:SK 6812 MINI-EA | C5378731
MX_SK6812MINI-EA | LED56 | MoonBoard:SK 6812 MINI-EA | C5378731
MX_SK6812MINI-EA | LED57 | MoonBoard:SK 6812 MINI-EA | C5378731
MX_SK6812MINI-EA | LED58 | MoonBoard:SK 6812 MINI-EA | C5378731
MX_SK6812MINI-EA | LED59 | MoonBoard:SK 6812 MINI-EA | C5378731
MX_SK6812MINI-EA | LED60 | MoonBoard:SK 6812 MINI-EA | C5378731
MX_SK6812MINI-EA | LED61 | MoonBoard:SK 6812 MINI-EA | C5378731
MX_SK6812MINI-EA | LED62 | MoonBoard:SK 6812 MINI-EA | C5378731
MX_SK6812MINI-EA | LED63 | MoonBoard:SK 6812 MINI-EA | C5378731
MX_SK6812MINI-EA | LED64 | MoonBoard:SK 6812 MINI-EA | C5378731
MX_SK6812MINI-EA | LED65 | MoonBoard:SK 6812 MINI-EA | C5378731
MX_SK6812MINI-EA | LED66 | MoonBoard:SK 6812 MINI-EA | C5378731
MX_SK6812MINI-EA | LED67 | MoonBoard:SK 6812 MINI-EA | C5378731
MX_SK6812MINI-EA | LED68 | MoonBoard:SK 6812 MINI-EA | C5378731
MX_SK6812MINI-EA | LED69 | MoonBoard:SK 6812 MINI-EA | C5378731
AMS1117-3.3 | U1 | Package_TO_SOT_SMD:SOT-223-3_TabPin2 | C6186
120R @ 100MHz | FB2 | Inductor_SMD:L_0805_2012Metric | C79382

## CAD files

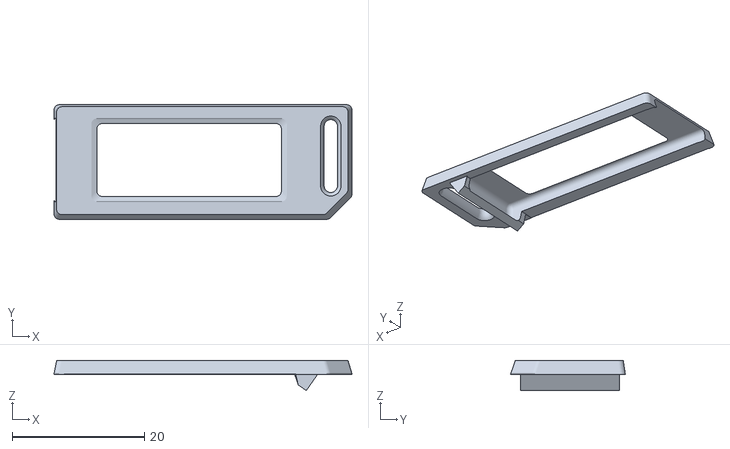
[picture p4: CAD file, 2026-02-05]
hardware/stl/prod-oled-cover.stl
45.0 x 17.3 x 4.55

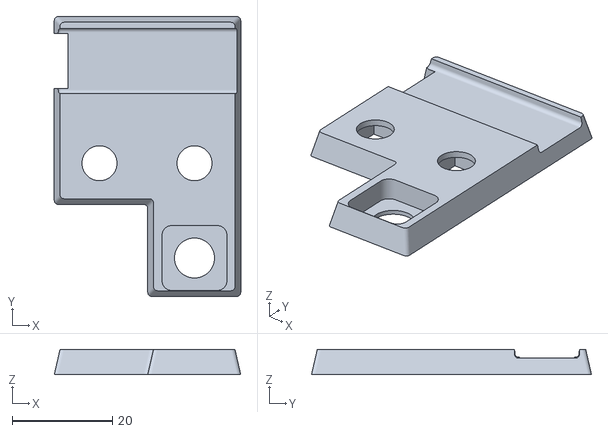
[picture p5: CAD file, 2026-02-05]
hardware/stl/prod-oled-base.stl
37.3 x 56.0 x 5.01

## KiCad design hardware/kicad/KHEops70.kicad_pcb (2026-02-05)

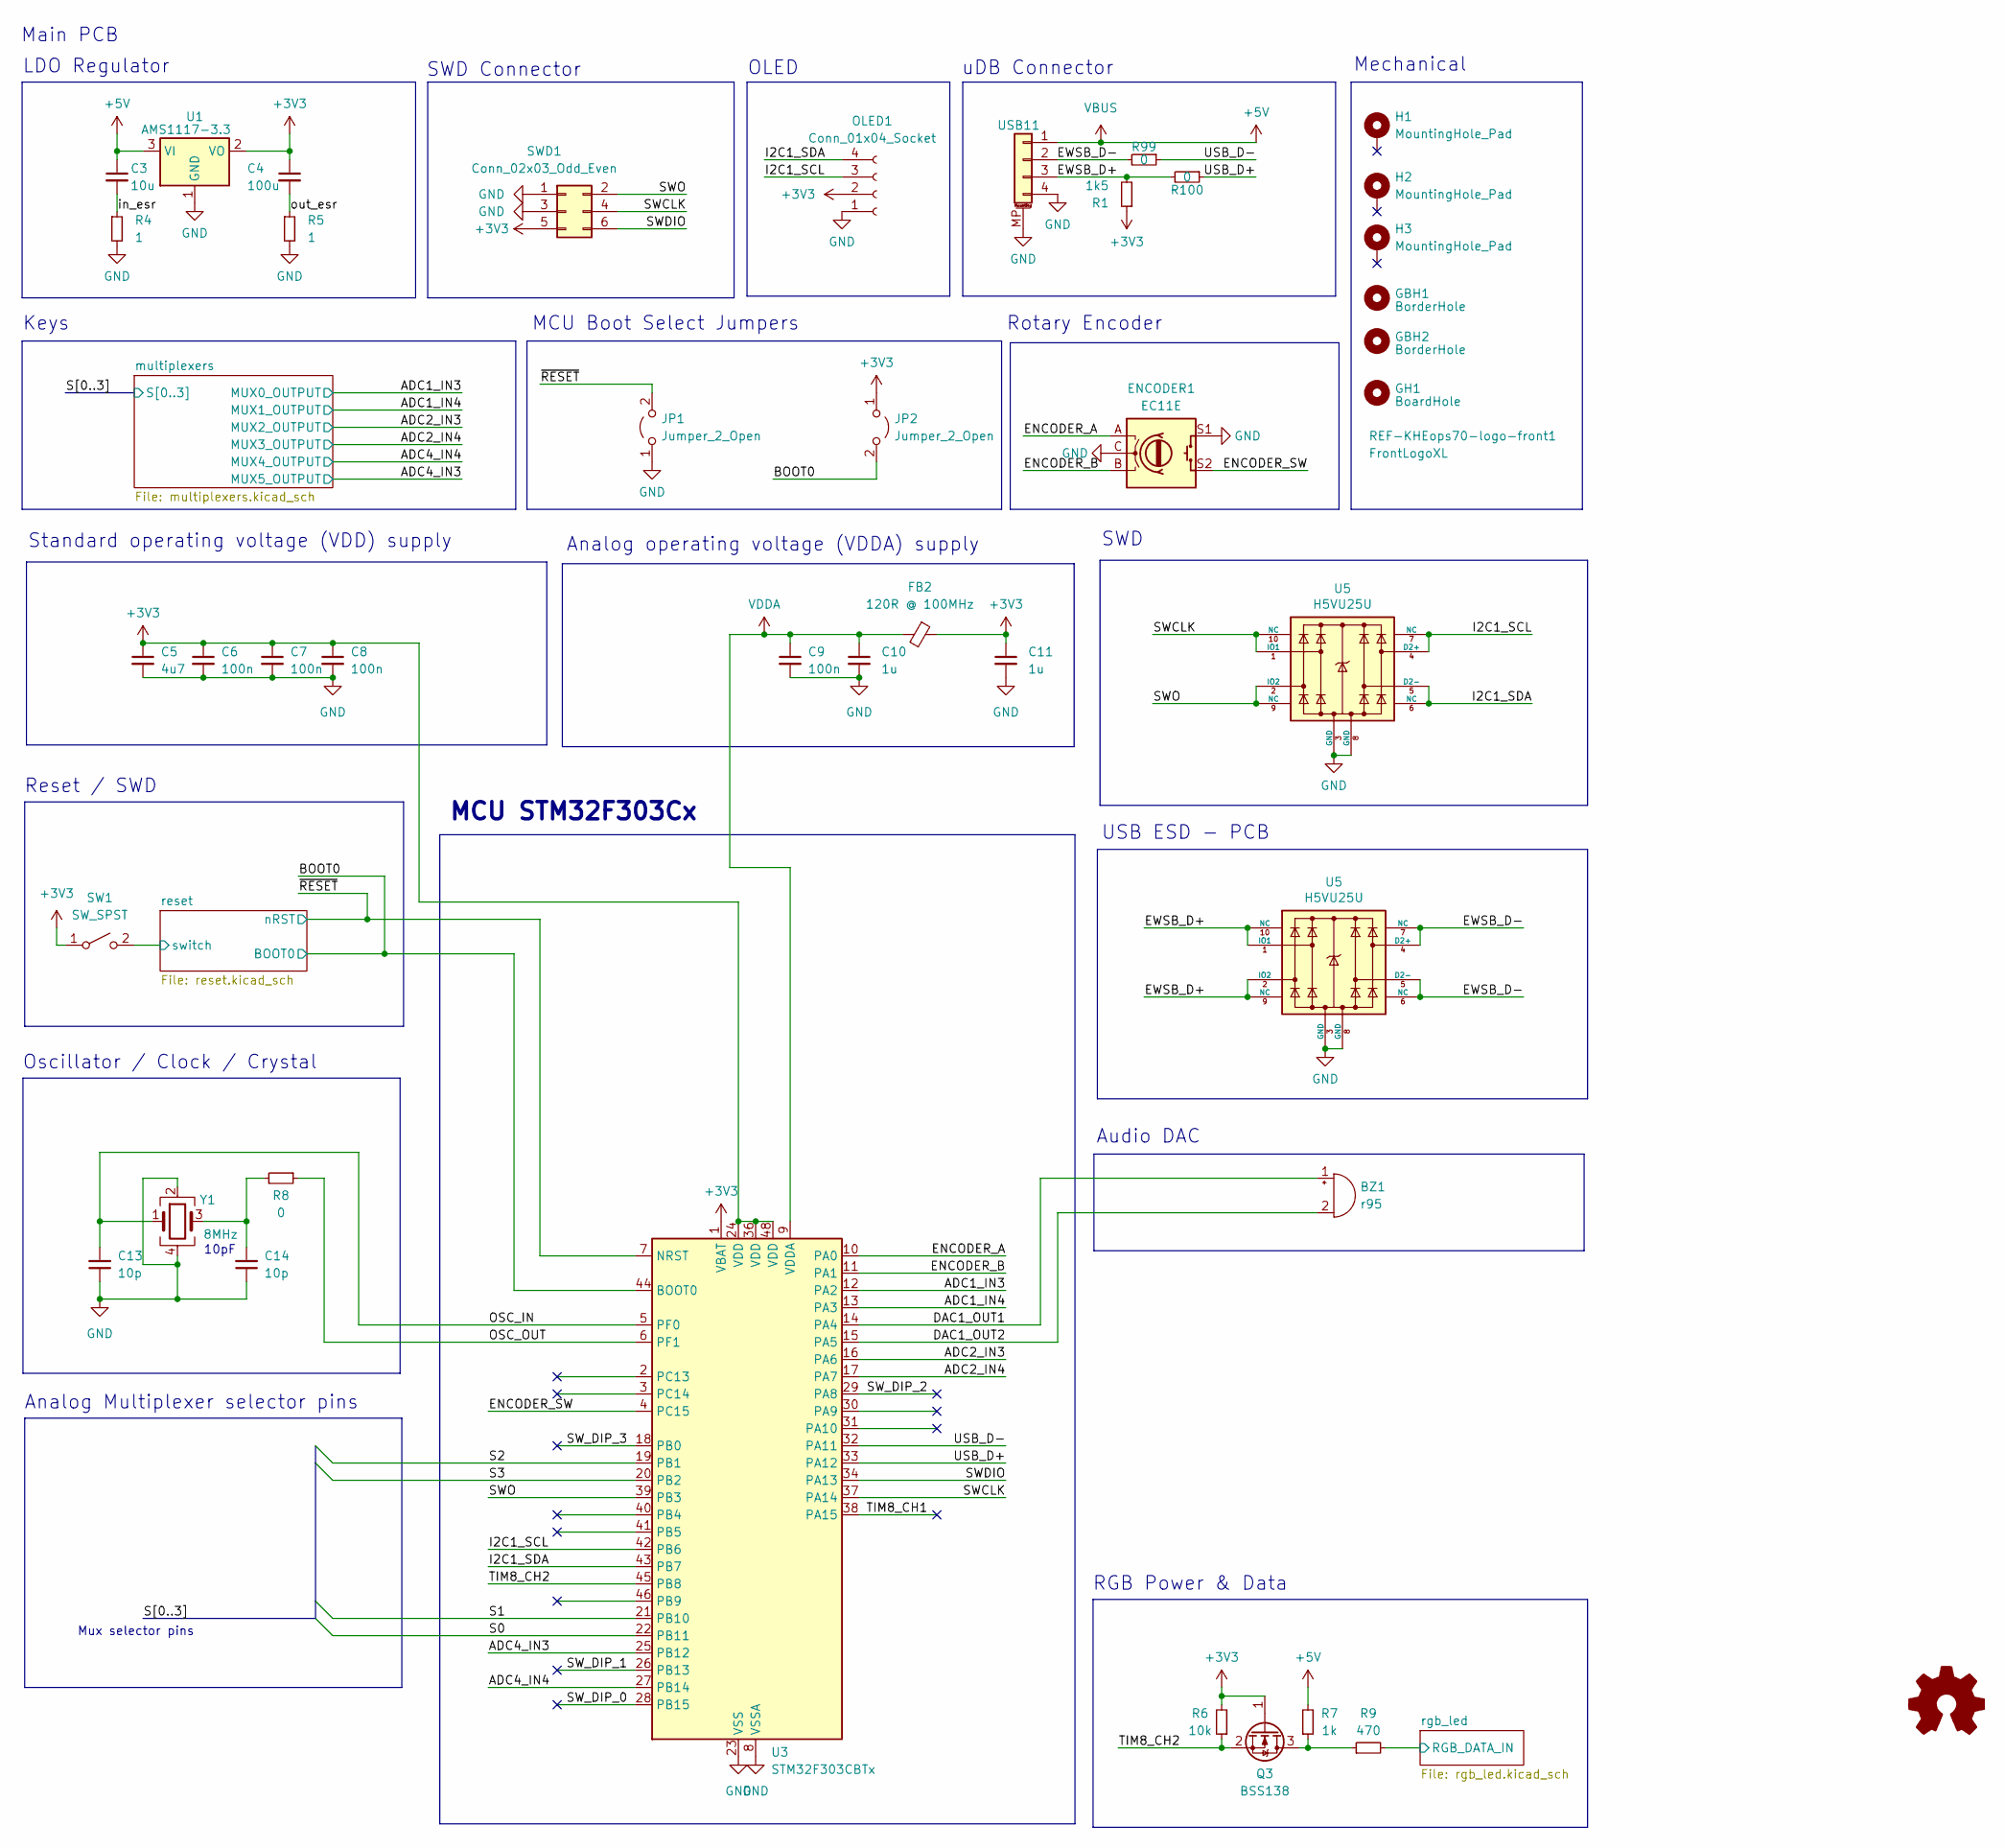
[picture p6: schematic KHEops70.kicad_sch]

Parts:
BZ1: r95; Buzzer_Murata_PKLCS1212E; LCSC PN C113159
C3: 10u; C_1206_3216Metric; LCSC C13585
C4: 100u; C_1206_3216Metric; LCSC C15008
C5: 4u7; C_0402_1005Metric; LCSC C23733
C6, C7, C8, C9: 100n; C_0402_1005Metric; LCSC C1525
C10, C11: 1u; C_0402_1005Metric; LCSC C52923
C13, C14: 10p; C_0402_1005Metric; LCSC C32949
ENCODER1: EC11E; ROT_Alps_EC11E-Switch
FB2: 120R @ 100MHz; L_0805_2012Metric; LCSC C79382
GBH1, GBH2: BorderHole; KHEops70-border-hole
GH1: BoardHole; KHEops70-hole
H1, H2, H3: MountingHole_Pad; 2.2mm hole
JP1, JP2: Jumper_2_Open; PinHeader_1x02_P2.54mm_Vertical
LOGO2: (no value)
OLED1: Conn_01x04_Socket; OLED Module
Q3: BSS138; SOT-23; LCSC C5224263
R1: 1k5; R_0805_2012Metric; LCSC C25867
R4, R5: 1; R_1206_3216Metric; LCSC C17928
R6: 10k; R_0805_2012Metric; LCSC C17414
R7: 1k; R_0805_2012Metric; LCSC C17513
R8, R99, R100: 0; R_0603_1608Metric_Pad0.98x0.95mm_HandSolder; LCSC C21189
R9: 470; R_0805_2012Metric; LCSC C25117
REF-KHEops70-logo-front1: FrontLogoXL; KHEops70-logo-xl
SW1: SW_SPST; SW_SPST_TL3342; LCSC C2886897
SWD1: Conn_02x03_Odd_Even; PinHeader_2x03_P2.54mm_Vertical
U1: AMS1117-3.3; SOT-223-3_TabPin2; LCSC C6186
U3: STM32F303CBTx; LQFP-48_7x7mm_P0.5mm; LCSC C108516
U5: H5VU25U; DFN2510; Manufacturer Part Number TPD4E05U06DQAR; LCSC C20615800
USB11: SM04B-SRSS-TB; JST_SH_SM04B-SRSS-TB_1x04-1MP_P1.00mm_Horizontal; Manufacturer Part Number SM04B-SRSS-TB; LCSC C160404
Y1: 8MHz; Crystal_SMD_3225-4Pin_3.2x2.5mm; LCSC C518154

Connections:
+3V3: C4.1, C5.1, C6.1, C7.1, C8.1, C11.1, FB2.1, JP2.1 (A), OLED1.2, Q3.1 (G), R1.1, R6.2, SW1.1 (A), SWD1.5, U1.2 (VO), U3.1 (VBAT), U3.24 (VDD), U3.36 (VDD), U3.48 (VDD); also elsewhere on the board
+5V: C3.1, R7.2, U1.3 (VI), USB11.1; also elsewhere on the board
/ADC1_IN3: U3.12 (PA2); also elsewhere on the board
/ADC2_IN3: U3.16 (PA6); also elsewhere on the board
/ADC2_IN4: U3.17 (PA7); also elsewhere on the board
/ADC4_IN3: U3.25 (PB12); also elsewhere on the board
/ADC4_IN4: U3.27 (PB14); also elsewhere on the board
/BOOT0: JP2.2 (B), U3.44 (BOOT0); also elsewhere on the board
/DAC1_OUT1: BZ1.1 (-), U3.14 (PA4)
/DAC1_OUT2: BZ1.2 (+), U3.15 (PA5)
/ENCODER_A: ENCODER1.A, U3.10 (PA0)
/ENCODER_B: ENCODER1.B, U3.11 (PA1)
/ENCODER_SW: ENCODER1.S2, U3.4 (PC15)
/OSC_IN: C13.2, U3.5 (PF0), Y1.1
/OSC_OUT: R8.1, U3.6 (PF1)
/S1: U3.21 (PB10); also elsewhere on the board
/S2: U3.19 (PB1); also elsewhere on the board
/S3: U3.20 (PB2); also elsewhere on the board
/SWDIO: SWD1.6, U3.34 (PA13)
/SW_DIP_0: U3.28 (PB15)
/SW_DIP_1: U3.26 (PB13)
/SW_DIP_2: U3.29 (PA8)
/SW_DIP_3: U3.18 (PB0)
/TIM8_CH1: U3.38 (PA15)
/TIM8_CH2: Q3.2 (S), R6.1, U3.45 (PB8)
/USB_D+: R100.1, U3.33 (PA12)
/USB_D-: R99.1, U3.32 (PA11)
/in_esr: C3.2, R4.1
/out_esr: C4.2, R5.1
/reset/switch: SW1.2 (B); also elsewhere on the board
/rgb_led/RGB_DATA_IN: R9.2; also elsewhere on the board
/~RESET: JP1.2 (B), U3.7 (NRST); also elsewhere on the board
unnamed: C14.2, R8.2, Y1.3
unnamed: Q3.3 (D), R7.1, R9.1
VDDA: C9.1, C10.1, FB2.2, U3.9 (VDDA)

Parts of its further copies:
U10, U11: H5VU25U; DFN2510; Manufacturer Part Number TPD4E05U06DQAR; LCSC C20615800

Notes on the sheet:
Standard operating voltage (VDD) supply
Mechanical
Keys
Analog Multiplexer selector pins
Mux selector pins
SWD Connector
SWD
OLED
Audio DAC
10pF
MCU Boot Select Jumpers
USB ESD - PCB
RGB Power & Data
Reset / SWD
Rotary Encoder
Analog operating voltage (VDDA) supply
uDB Connector
MCU STM32F303Cx
LDO Regulator
Main PCB
Oscillator / Clock / Crystal

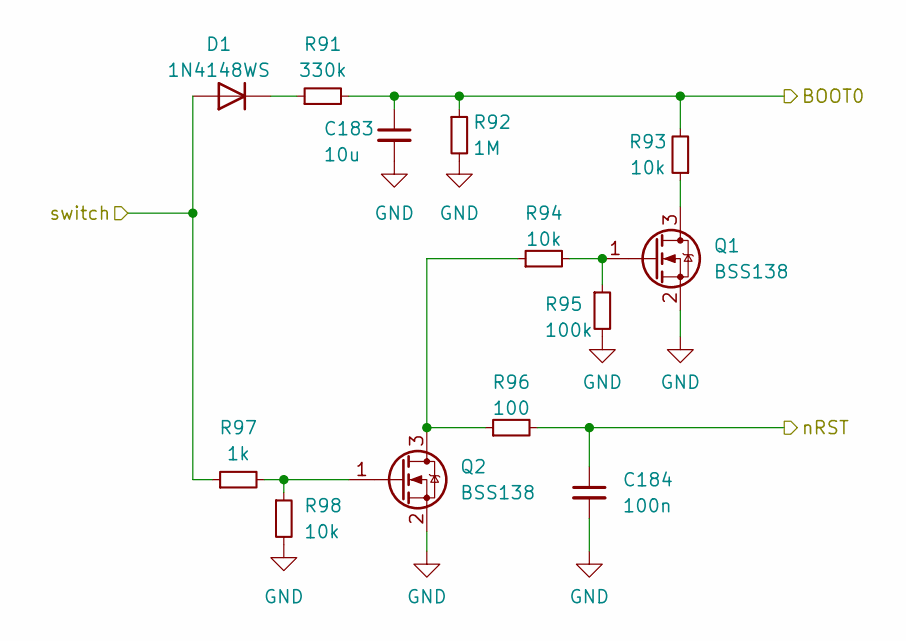
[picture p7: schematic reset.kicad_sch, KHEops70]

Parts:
C183: 10u; C_1206_3216Metric; LCSC C13585
C184: 100n; C_0805_2012Metric; LCSC C49678
D1: 1N4148WS; D_SOD-323; LCSC C2128
Q1, Q2: BSS138; SOT-23; LCSC C5224263
R91: 330k; R_0603_1608Metric; LCSC C23137
R92: 1M; R_0603_1608Metric; LCSC C22935
R93, R98: 10k; R_0603_1608Metric; LCSC C17414
R94: 10k; R_0805_2012Metric; LCSC C17414
R95: 100k; R_0805_2012Metric; LCSC C25741
R96: 100; R_0805_2012Metric; LCSC C25076
R97: 1k; R_0603_1608Metric; LCSC C21190

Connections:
/BOOT0: C183.1, R91.2, R92.1, R93.2; also elsewhere on the board
/reset/switch: D1.2 (A), R97.1; also elsewhere on the board
/~RESET: C184.1, R96.2; also elsewhere on the board
unnamed: D1.1 (K), R91.1
unnamed: Q1.3 (D), R93.1
unnamed: Q1.1 (G), R94.2, R95.1
unnamed: Q2.3 (D), R94.1, R96.1
unnamed: Q2.1 (G), R97.2, R98.1

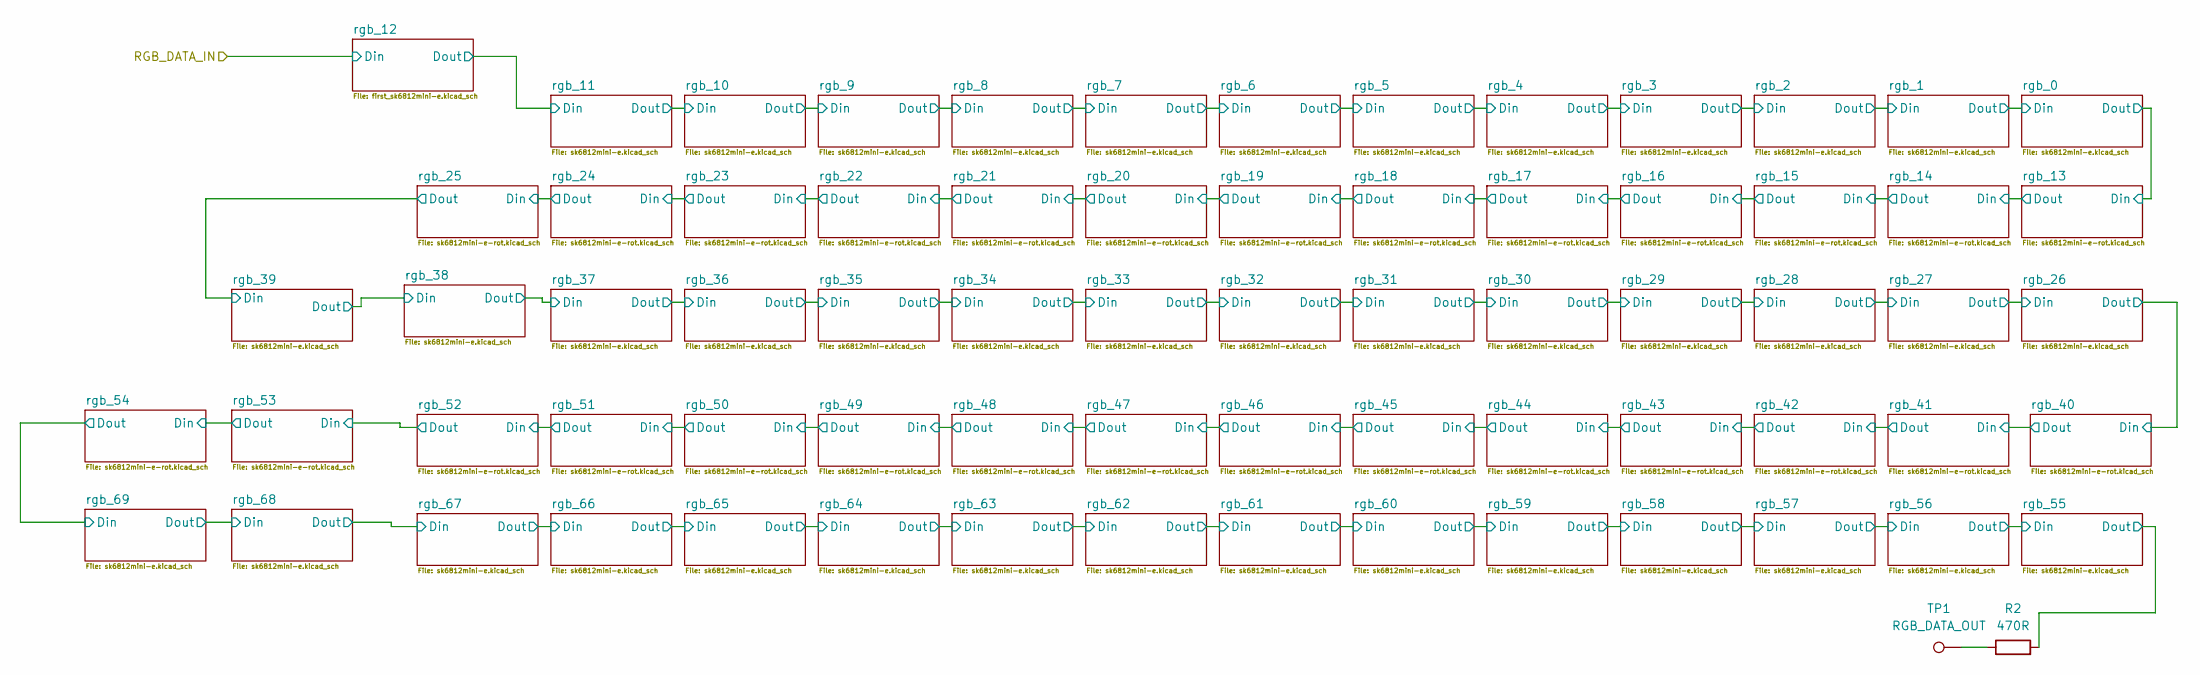
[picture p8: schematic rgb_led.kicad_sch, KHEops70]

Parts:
R2: 470R; R_0805_2012Metric; LCSC C25117
TP1: RGB_DATA_OUT; TestPoint_Pad_D1.5mm

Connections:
/rgb_led/rgb_55/Dout: R2.2; also elsewhere on the board
unnamed: R2.1, TP1.1

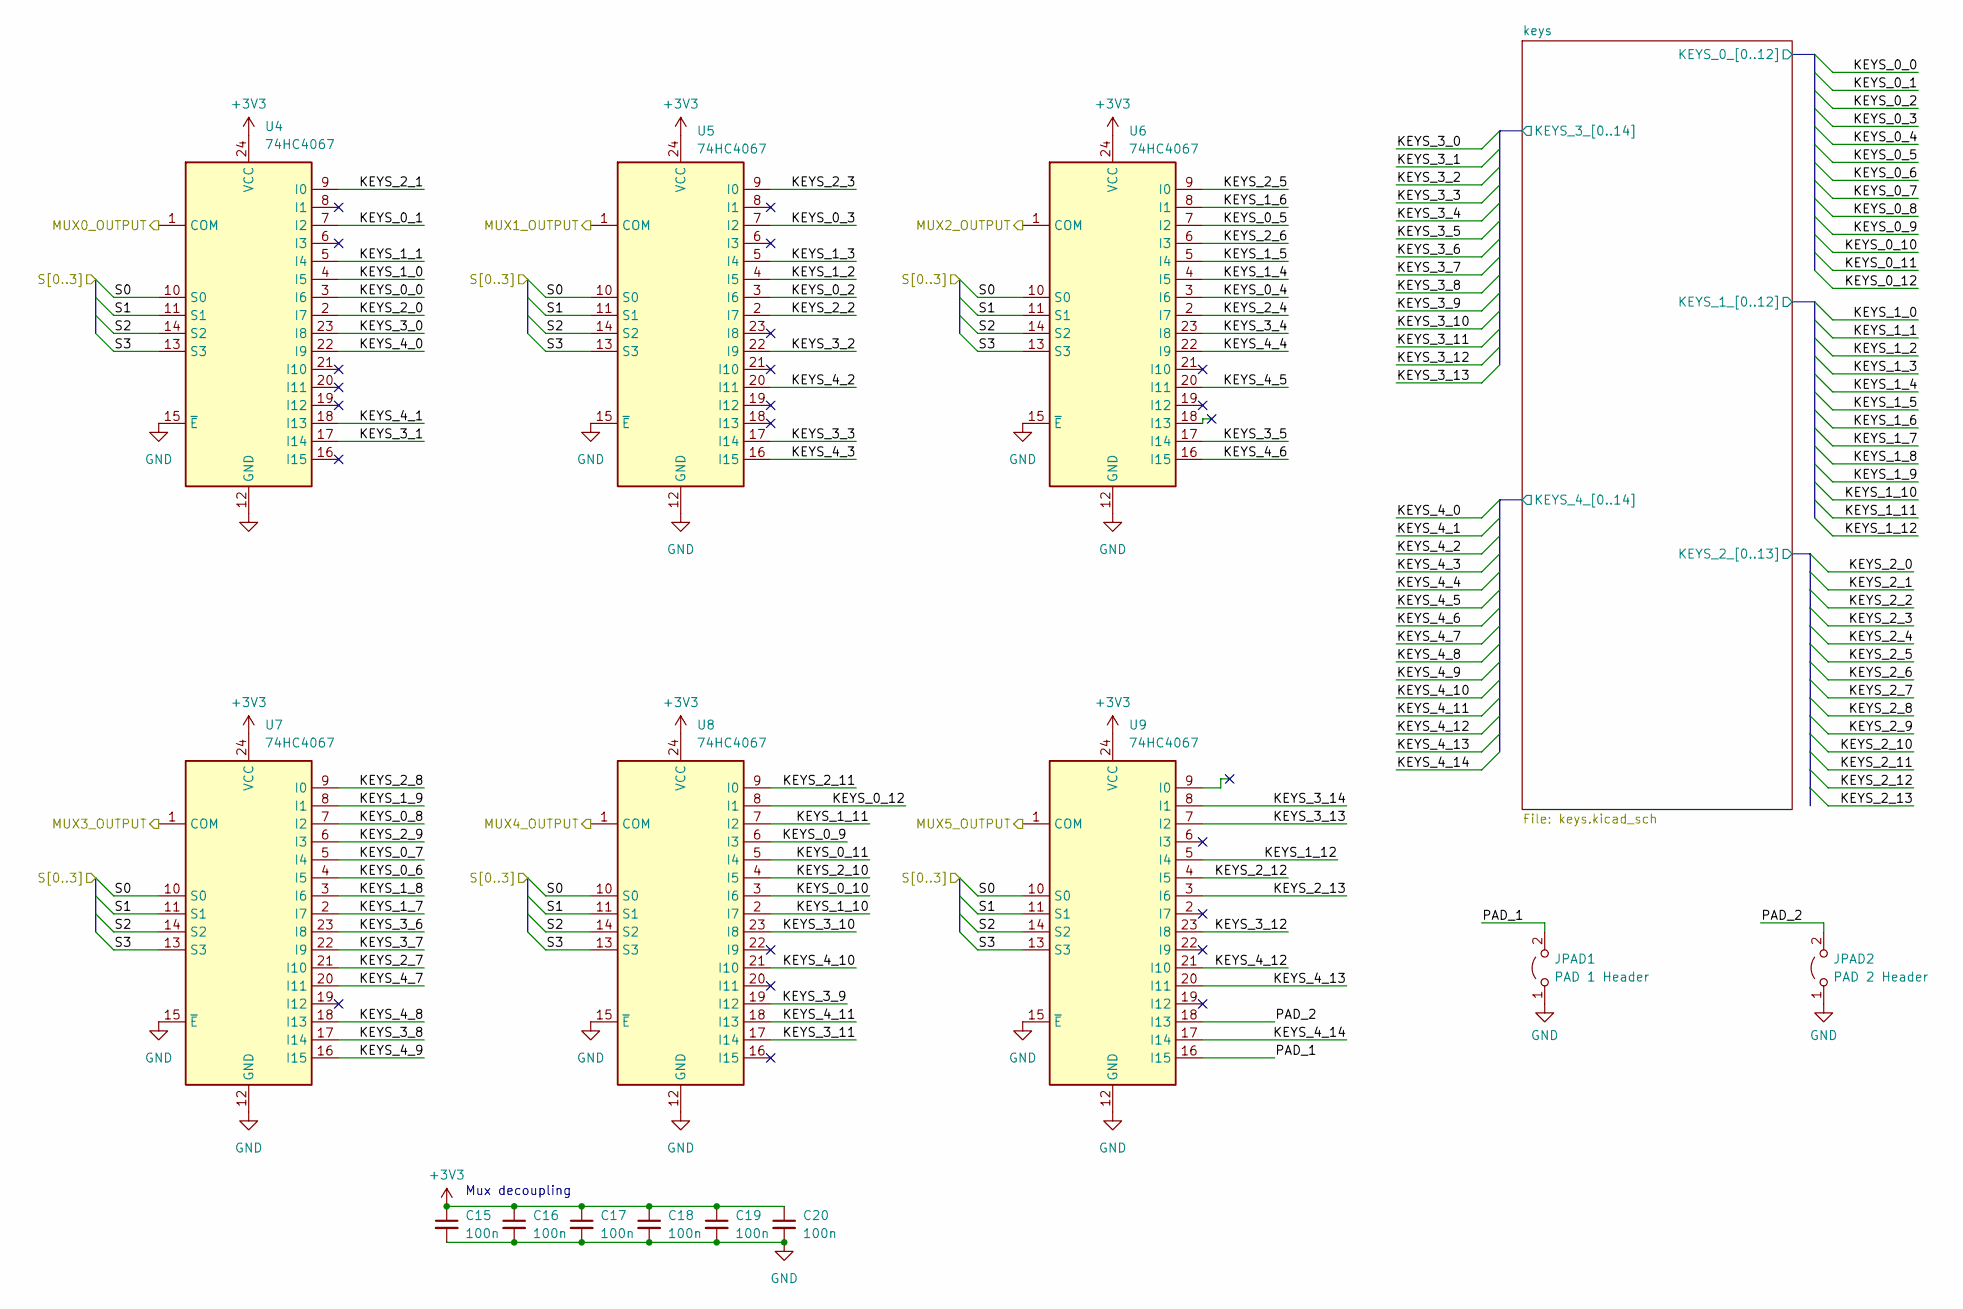
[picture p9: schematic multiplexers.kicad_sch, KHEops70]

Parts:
C15, C16, C17, C18, C19, C20: 100n; C_0805_2012Metric; LCSC C49678
JPAD1: PAD 1 Header; PinHeader_1x02_P2.54mm_Vertical
JPAD2: PAD 2 Header; PinHeader_1x02_P2.54mm_Vertical
U4, U5, U6, U7, U8, U9: 74HC4067; TSSOP-24_4.4x7.8mm_P0.65mm; LCSC C179326

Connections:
+3V3: C15.1, C16.1, C17.1, C18.1, C19.1, C20.1, U4.24 (VCC), U5.24 (VCC), U6.24 (VCC), U7.24 (VCC), U8.24 (VCC), U9.24 (VCC); also elsewhere on the board
/ADC1_IN3: U4.1 (COM); also elsewhere on the board
/ADC2_IN3: U6.1 (COM); also elsewhere on the board
/ADC2_IN4: U7.1 (COM); also elsewhere on the board
/ADC4_IN3: U9.1 (COM); also elsewhere on the board
/ADC4_IN4: U8.1 (COM); also elsewhere on the board
/S1: U4.11 (S1), U5.11 (S1), U6.11 (S1), U7.11 (S1), U8.11 (S1), U9.11 (S1); also elsewhere on the board
/S2: U4.14 (S2), U5.14 (S2), U6.14 (S2), U7.14 (S2), U8.14 (S2), U9.14 (S2); also elsewhere on the board
/S3: U4.13 (S3), U5.13 (S3), U6.13 (S3), U7.13 (S3), U8.13 (S3), U9.13 (S3); also elsewhere on the board
/multiplexers/PAD_1: JPAD1.2 (B), U9.16 (I15)
/multiplexers/PAD_2: JPAD2.2 (B), U9.18 (I13)
/multiplexers/keys/KEYS_0_0: U4.3 (I6); also elsewhere on the board
/multiplexers/keys/KEYS_0_1: U4.7 (I2); also elsewhere on the board
/multiplexers/keys/KEYS_0_4: U6.3 (I6); also elsewhere on the board
/multiplexers/keys/KEYS_0_5: U6.7 (I2); also elsewhere on the board
/multiplexers/keys/KEYS_0_6: U7.4 (I5); also elsewhere on the board
/multiplexers/keys/KEYS_0_7: U7.5 (I4); also elsewhere on the board
/multiplexers/keys/KEYS_0_8: U7.7 (I2); also elsewhere on the board
/multiplexers/keys/KEYS_0_9: U8.6 (I3); also elsewhere on the board
/multiplexers/keys/KEYS_0_10: U8.3 (I6); also elsewhere on the board
/multiplexers/keys/KEYS_0_11: U8.5 (I4); also elsewhere on the board
/multiplexers/keys/KEYS_0_12: U8.8 (I1); also elsewhere on the board
/multiplexers/keys/KEYS_1_0: U4.4 (I5); also elsewhere on the board
/multiplexers/keys/KEYS_1_1: U4.5 (I4); also elsewhere on the board
/multiplexers/keys/KEYS_1_4: U6.4 (I5); also elsewhere on the board
/multiplexers/keys/KEYS_1_5: U6.5 (I4); also elsewhere on the board
/multiplexers/keys/KEYS_1_6: U6.8 (I1); also elsewhere on the board
/multiplexers/keys/KEYS_1_7: U7.2 (I7); also elsewhere on the board
/multiplexers/keys/KEYS_1_8: U7.3 (I6); also elsewhere on the board
/multiplexers/keys/KEYS_1_9: U7.8 (I1); also elsewhere on the board
/multiplexers/keys/KEYS_1_10: U8.2 (I7); also elsewhere on the board
/multiplexers/keys/KEYS_1_11: U8.7 (I2); also elsewhere on the board
/multiplexers/keys/KEYS_1_12: U9.5 (I4); also elsewhere on the board
/multiplexers/keys/KEYS_2_0: U4.2 (I7); also elsewhere on the board
/multiplexers/keys/KEYS_2_1: U4.9 (I0); also elsewhere on the board
/multiplexers/keys/KEYS_2_4: U6.2 (I7); also elsewhere on the board
/multiplexers/keys/KEYS_2_5: U6.9 (I0); also elsewhere on the board
/multiplexers/keys/KEYS_2_6: U6.6 (I3); also elsewhere on the board
/multiplexers/keys/KEYS_2_7: U7.21 (I10); also elsewhere on the board
/multiplexers/keys/KEYS_2_8: U7.9 (I0); also elsewhere on the board
/multiplexers/keys/KEYS_2_9: U7.6 (I3); also elsewhere on the board
/multiplexers/keys/KEYS_2_10: U8.4 (I5); also elsewhere on the board
/multiplexers/keys/KEYS_2_11: U8.9 (I0); also elsewhere on the board
/multiplexers/keys/KEYS_2_12: U9.4 (I5); also elsewhere on the board
/multiplexers/keys/KEYS_2_13: U9.3 (I6); also elsewhere on the board
/multiplexers/keys/KEYS_3_0: U4.23 (I8); also elsewhere on the board
/multiplexers/keys/KEYS_3_1: U4.17 (I14); also elsewhere on the board
/multiplexers/keys/KEYS_3_2: U5.22 (I9); also elsewhere on the board
/multiplexers/keys/KEYS_3_3: U5.17 (I14); also elsewhere on the board
/multiplexers/keys/KEYS_3_4: U6.23 (I8); also elsewhere on the board
/multiplexers/keys/KEYS_3_5: U6.17 (I14); also elsewhere on the board
/multiplexers/keys/KEYS_3_6: U7.23 (I8); also elsewhere on the board
/multiplexers/keys/KEYS_3_7: U7.22 (I9); also elsewhere on the board
/multiplexers/keys/KEYS_3_8: U7.17 (I14); also elsewhere on the board
/multiplexers/keys/KEYS_3_9: U8.19 (I12); also elsewhere on the board
/multiplexers/keys/KEYS_3_10: U8.23 (I8); also elsewhere on the board
/multiplexers/keys/KEYS_3_11: U8.17 (I14); also elsewhere on the board
/multiplexers/keys/KEYS_3_12: U9.23 (I8); also elsewhere on the board
/multiplexers/keys/KEYS_3_13: U9.7 (I2); also elsewhere on the board
/multiplexers/keys/KEYS_3_14: U9.8 (I1); also elsewhere on the board
/multiplexers/keys/KEYS_4_0: U4.22 (I9); also elsewhere on the board
/multiplexers/keys/KEYS_4_1: U4.18 (I13); also elsewhere on the board
/multiplexers/keys/KEYS_4_2: U5.20 (I11); also elsewhere on the board
/multiplexers/keys/KEYS_4_3: U5.16 (I15); also elsewhere on the board
/multiplexers/keys/KEYS_4_4: U6.22 (I9); also elsewhere on the board
/multiplexers/keys/KEYS_4_5: U6.20 (I11); also elsewhere on the board
/multiplexers/keys/KEYS_4_6: U6.16 (I15); also elsewhere on the board
/multiplexers/keys/KEYS_4_7: U7.20 (I11); also elsewhere on the board
/multiplexers/keys/KEYS_4_8: U7.18 (I13); also elsewhere on the board
/multiplexers/keys/KEYS_4_9: U7.16 (I15); also elsewhere on the board
/multiplexers/keys/KEYS_4_10: U8.21 (I10); also elsewhere on the board
/multiplexers/keys/KEYS_4_11: U8.18 (I13); also elsewhere on the board
/multiplexers/keys/KEYS_4_12: U9.21 (I10); also elsewhere on the board
/multiplexers/keys/KEYS_4_13: U9.20 (I11); also elsewhere on the board
/multiplexers/keys/KEYS_4_14: U9.17 (I14); also elsewhere on the board

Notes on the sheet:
Mux decoupling

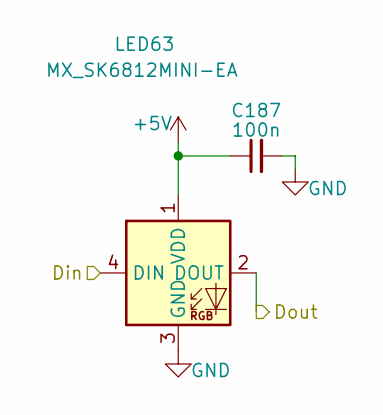
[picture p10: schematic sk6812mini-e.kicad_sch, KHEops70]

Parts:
C187: 100n; C_0805_2012Metric; LCSC C49678
LED63: MX_SK6812MINI-EA; SK 6812 MINI-EA; LCSC C5378731

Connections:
+5V: C187.1, LED63.1 (VDD); also elsewhere on the board
/rgb_led/rgb_62/Din: LED63.2 (DOUT); also elsewhere on the board
/rgb_led/rgb_63/Din: LED63.4 (DIN); also elsewhere on the board

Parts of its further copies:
C74, C101, C102, C103, C104, C131, C132, C163, C164, C165, C166, C167, C168, C169, C170, C171, C172, C173, C174, C175, C176, C177, C178, C179, C180, C181, C182, C185, C186, C188, C189, C190, C191, C192, C193, C194, C195, C268, C271, C274: 100n; C_0805_2012Metric; LCSC C49678
LED0, LED1, LED2, LED3, LED4, LED5, LED6, LED7, LED8, LED9, LED10, LED11, LED26, LED27, LED28, LED29, LED30, LED31, LED32, LED33, LED34, LED35, LED36, LED37, LED38, LED39, LED55, LED56, LED57, LED58, LED59, LED60, LED61, LED62, LED64, LED65, LED66, LED67, LED68, LED69: MX_SK6812MINI-EA; SK 6812 MINI-EA; LCSC C5378731

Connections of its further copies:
+5V: C74.1, C101.1, C102.1, C103.1, C104.1, C131.1, C132.1, C163.1, C164.1, C165.1, C166.1, C167.1, C168.1, C169.1, C170.1, C171.1, C172.1, C173.1, C174.1, C175.1, C176.1, C177.1, C178.1, C179.1, C180.1, C181.1, C182.1, C185.1, C186.1, C188.1, C189.1, C190.1, C191.1, C192.1, C193.1, C194.1, C195.1, C268.1, C271.1, C274.1, LED0.1 (VDD), LED1.1 (VDD), LED2.1 (VDD), LED3.1 (VDD), LED4.1 (VDD), LED5.1 (VDD), LED6.1 (VDD), LED7.1 (VDD), LED8.1 (VDD), LED9.1 (VDD), LED10.1 (VDD), LED11.1 (VDD), LED26.1 (VDD), LED27.1 (VDD), LED28.1 (VDD), LED29.1 (VDD), LED30.1 (VDD), LED31.1 (VDD), LED32.1 (VDD), LED33.1 (VDD), LED34.1 (VDD), LED35.1 (VDD), LED36.1 (VDD), LED37.1 (VDD), LED38.1 (VDD), LED39.1 (VDD), LED55.1 (VDD), LED56.1 (VDD), LED57.1 (VDD), LED58.1 (VDD), LED59.1 (VDD), LED60.1 (VDD), LED61.1 (VDD), LED62.1 (VDD), LED64.1 (VDD), LED65.1 (VDD), LED66.1 (VDD), LED67.1 (VDD), LED68.1 (VDD), LED69.1 (VDD); also elsewhere on the board
/rgb_led/rgb_0/Din: LED0.4 (DIN), LED1.2 (DOUT)
/rgb_led/rgb_0/Dout: LED0.2 (DOUT); also elsewhere on the board
/rgb_led/rgb_1/Din: LED1.4 (DIN), LED2.2 (DOUT)
/rgb_led/rgb_2/Din: LED2.4 (DIN), LED3.2 (DOUT)
/rgb_led/rgb_3/Din: LED3.4 (DIN), LED4.2 (DOUT)
/rgb_led/rgb_4/Din: LED4.4 (DIN), LED5.2 (DOUT)
/rgb_led/rgb_5/Din: LED5.4 (DIN), LED6.2 (DOUT)
/rgb_led/rgb_6/Din: LED6.4 (DIN), LED7.2 (DOUT)
/rgb_led/rgb_7/Din: LED7.4 (DIN), LED8.2 (DOUT)
/rgb_led/rgb_8/Din: LED8.4 (DIN), LED9.2 (DOUT)
/rgb_led/rgb_10/Din: LED10.4 (DIN), LED11.2 (DOUT)
/rgb_led/rgb_10/Dout: LED9.4 (DIN), LED10.2 (DOUT)
/rgb_led/rgb_11/Din: LED11.4 (DIN); also elsewhere on the board
/rgb_led/rgb_25/Dout: LED39.4 (DIN); also elsewhere on the board
/rgb_led/rgb_26/Din: LED26.4 (DIN), LED27.2 (DOUT)
/rgb_led/rgb_26/Dout: LED26.2 (DOUT); also elsewhere on the board
/rgb_led/rgb_27/Din: LED27.4 (DIN), LED28.2 (DOUT)
/rgb_led/rgb_28/Din: LED28.4 (DIN), LED29.2 (DOUT)
/rgb_led/rgb_29/Din: LED29.4 (DIN), LED30.2 (DOUT)
/rgb_led/rgb_30/Din: LED30.4 (DIN), LED31.2 (DOUT)
/rgb_led/rgb_31/Din: LED31.4 (DIN), LED32.2 (DOUT)
/rgb_led/rgb_32/Din: LED32.4 (DIN), LED33.2 (DOUT)
/rgb_led/rgb_33/Din: LED33.4 (DIN), LED34.2 (DOUT)
/rgb_led/rgb_34/Din: LED34.4 (DIN), LED35.2 (DOUT)
/rgb_led/rgb_35/Din: LED35.4 (DIN), LED36.2 (DOUT)
/rgb_led/rgb_36/Din: LED36.4 (DIN), LED37.2 (DOUT)
/rgb_led/rgb_37/Din: LED37.4 (DIN), LED38.2 (DOUT)
/rgb_led/rgb_38/Din: LED38.4 (DIN), LED39.2 (DOUT)
/rgb_led/rgb_54/Dout: LED69.4 (DIN); also elsewhere on the board
/rgb_led/rgb_55/Din: LED55.4 (DIN), LED56.2 (DOUT)
/rgb_led/rgb_55/Dout: LED55.2 (DOUT); also elsewhere on the board
/rgb_led/rgb_56/Din: LED56.4 (DIN), LED57.2 (DOUT)
/rgb_led/rgb_57/Din: LED57.4 (DIN), LED58.2 (DOUT)
/rgb_led/rgb_58/Din: LED58.4 (DIN), LED59.2 (DOUT)
/rgb_led/rgb_59/Din: LED59.4 (DIN), LED60.2 (DOUT)
/rgb_led/rgb_60/Din: LED60.4 (DIN), LED61.2 (DOUT)
/rgb_led/rgb_61/Din: LED61.4 (DIN), LED62.2 (DOUT)
/rgb_led/rgb_62/Din: LED62.4 (DIN); also elsewhere on the board
/rgb_led/rgb_63/Din: LED64.2 (DOUT); also elsewhere on the board
/rgb_led/rgb_64/Din: LED64.4 (DIN), LED65.2 (DOUT)
/rgb_led/rgb_65/Din: LED65.4 (DIN), LED66.2 (DOUT)
/rgb_led/rgb_66/Din: LED66.4 (DIN), LED67.2 (DOUT)
/rgb_led/rgb_67/Din: LED67.4 (DIN), LED68.2 (DOUT)
/rgb_led/rgb_68/Din: LED68.4 (DIN), LED69.2 (DOUT)

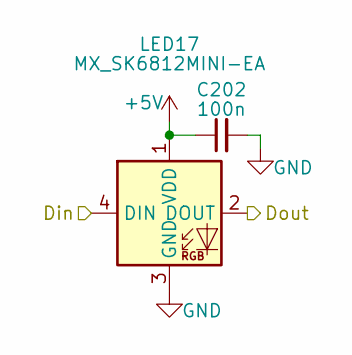
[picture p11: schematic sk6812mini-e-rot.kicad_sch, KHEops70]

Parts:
C202: 100n; C_0805_2012Metric; LCSC C49678
LED17: MX_SK6812MINI-EA; SK 6812 MINI-EA-ROT; LCSC C5378731

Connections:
+5V: C202.1, LED17.1 (VDD); also elsewhere on the board
/rgb_led/rgb_16/Dout: LED17.4 (DIN); also elsewhere on the board
/rgb_led/rgb_17/Dout: LED17.2 (DOUT); also elsewhere on the board

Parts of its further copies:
C198, C199, C200, C201, C203, C204, C205, C206, C207, C208, C209, C210, C225, C226, C227, C228, C229, C230, C231, C232, C233, C234, C235, C236, C237, C262, C265: 100n; C_0805_2012Metric; LCSC C49678
LED13, LED14, LED15, LED16, LED18, LED19, LED20, LED21, LED22, LED23, LED24, LED25, LED40, LED41, LED42, LED43, LED44, LED45, LED46, LED47, LED48, LED49, LED50, LED51, LED52, LED53, LED54: MX_SK6812MINI-EA; SK 6812 MINI-EA-ROT; LCSC C5378731

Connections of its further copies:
+5V: C198.1, C199.1, C200.1, C201.1, C203.1, C204.1, C205.1, C206.1, C207.1, C208.1, C209.1, C210.1, C225.1, C226.1, C227.1, C228.1, C229.1, C230.1, C231.1, C232.1, C233.1, C234.1, C235.1, C236.1, C237.1, C262.1, C265.1, LED13.1 (VDD), LED14.1 (VDD), LED15.1 (VDD), LED16.1 (VDD), LED18.1 (VDD), LED19.1 (VDD), LED20.1 (VDD), LED21.1 (VDD), LED22.1 (VDD), LED23.1 (VDD), LED24.1 (VDD), LED25.1 (VDD), LED40.1 (VDD), LED41.1 (VDD), LED42.1 (VDD), LED43.1 (VDD), LED44.1 (VDD), LED45.1 (VDD), LED46.1 (VDD), LED47.1 (VDD), LED48.1 (VDD), LED49.1 (VDD), LED50.1 (VDD), LED51.1 (VDD), LED52.1 (VDD), LED53.1 (VDD), LED54.1 (VDD); also elsewhere on the board
/rgb_led/rgb_0/Dout: LED13.4 (DIN); also elsewhere on the board
/rgb_led/rgb_13/Dout: LED13.2 (DOUT), LED14.4 (DIN)
/rgb_led/rgb_14/Dout: LED14.2 (DOUT), LED15.4 (DIN)
/rgb_led/rgb_15/Dout: LED15.2 (DOUT), LED16.4 (DIN)
/rgb_led/rgb_16/Dout: LED16.2 (DOUT); also elsewhere on the board
/rgb_led/rgb_17/Dout: LED18.4 (DIN); also elsewhere on the board
/rgb_led/rgb_18/Dout: LED18.2 (DOUT), LED19.4 (DIN)
/rgb_led/rgb_19/Dout: LED19.2 (DOUT), LED20.4 (DIN)
/rgb_led/rgb_20/Dout: LED20.2 (DOUT), LED21.4 (DIN)
/rgb_led/rgb_21/Dout: LED21.2 (DOUT), LED22.4 (DIN)
/rgb_led/rgb_22/Dout: LED22.2 (DOUT), LED23.4 (DIN)
/rgb_led/rgb_23/Dout: LED23.2 (DOUT), LED24.4 (DIN)
/rgb_led/rgb_24/Dout: LED24.2 (DOUT), LED25.4 (DIN)
/rgb_led/rgb_25/Dout: LED25.2 (DOUT); also elsewhere on the board
/rgb_led/rgb_26/Dout: LED40.4 (DIN); also elsewhere on the board
/rgb_led/rgb_40/Dout: LED40.2 (DOUT), LED41.4 (DIN)
/rgb_led/rgb_41/Dout: LED41.2 (DOUT), LED42.4 (DIN)
/rgb_led/rgb_42/Dout: LED42.2 (DOUT), LED43.4 (DIN)
/rgb_led/rgb_43/Dout: LED43.2 (DOUT), LED44.4 (DIN)
/rgb_led/rgb_44/Dout: LED44.2 (DOUT), LED45.4 (DIN)
/rgb_led/rgb_45/Dout: LED45.2 (DOUT), LED46.4 (DIN)
/rgb_led/rgb_46/Dout: LED46.2 (DOUT), LED47.4 (DIN)
/rgb_led/rgb_47/Dout: LED47.2 (DOUT), LED48.4 (DIN)
/rgb_led/rgb_48/Dout: LED48.2 (DOUT), LED49.4 (DIN)
/rgb_led/rgb_49/Dout: LED49.2 (DOUT), LED50.4 (DIN)
/rgb_led/rgb_50/Dout: LED50.2 (DOUT), LED51.4 (DIN)
/rgb_led/rgb_51/Dout: LED51.2 (DOUT), LED52.4 (DIN)
/rgb_led/rgb_52/Dout: LED52.2 (DOUT), LED53.4 (DIN)
/rgb_led/rgb_53/Dout: LED53.2 (DOUT), LED54.4 (DIN)
/rgb_led/rgb_54/Dout: LED54.2 (DOUT); also elsewhere on the board

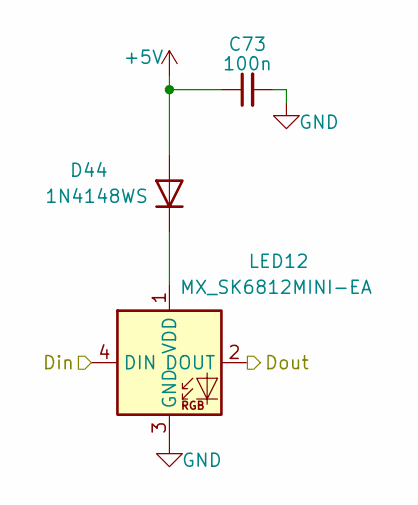
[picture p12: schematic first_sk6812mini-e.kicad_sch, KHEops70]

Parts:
C73: 100n; C_0805_2012Metric; LCSC C49678
D44: 1N4148WS; D_SOD-323; LCSC C2128
LED12: MX_SK6812MINI-EA; SK 6812 MINI-EA; LCSC C5378731

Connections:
+5V: C73.1, D44.2 (A); also elsewhere on the board
/rgb_led/RGB_DATA_IN: LED12.4 (DIN); also elsewhere on the board
/rgb_led/rgb_11/Din: LED12.2 (DOUT); also elsewhere on the board
unnamed: D44.1 (K), LED12.1 (VDD)

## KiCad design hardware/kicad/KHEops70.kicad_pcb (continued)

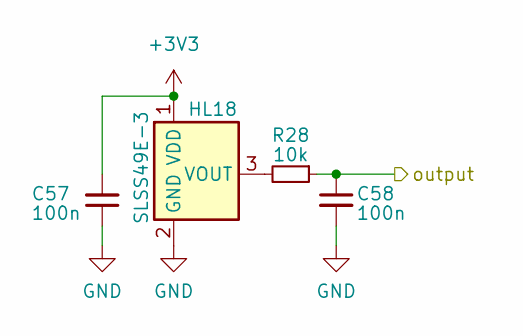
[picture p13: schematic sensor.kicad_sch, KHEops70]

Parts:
C57, C58: 100n; C_0805_2012Metric; LCSC C49678
HL18: SLSS49E-3; SLSS49E-3 with MX holes; LCSC C2904393
R28: 10k; R_0805_2012Metric; LCSC C17414

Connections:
+3V3: C57.2, HL18.1 (VDD); also elsewhere on the board
/multiplexers/keys/KEYS_1_5: C58.1, R28.1; also elsewhere on the board
unnamed: HL18.3 (VOUT), R28.2

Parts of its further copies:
C21, C22, C23, C24, C25, C26, C27, C28, C29, C30, C31, C32, C33, C34, C35, C36, C37, C38, C39, C40, C41, C42, C43, C44, C45, C46, C47, C48, C49, C50, C51, C52, C53, C54, C55, C56, C59, C60, C61, C62, C63, C64, C65, C66, C67, C68, C69, C70, C71, C72, C75, C76, C77, C78, C79, C80, C81, C82, C83, C84, C85, C86, C87, C88, C89, C90, C91, C92, C93, C94, C95, C96, C97, C98, C99, C100, C105, C106, C107, C108, C109, C110, C111, C112, C113, C114, C115, C116, C117, C118, C119, C120, C121, C122, C123, C124, C125, C126, C127, C128, C129, C130, C133, C134, C135, C136, C137, C138, C139, C140, C141, C142, C143, C144, C145, C146, C147, C148, C149, C150, C151, C152, C153, C154, C155, C156, C157, C158, C260, C261, C263, C264, C266, C267, C269, C270, C272, C273: 100n; C_0805_2012Metric; LCSC C49678
HL0, HL1, HL2, HL3, HL4, HL5, HL6, HL7, HL8, HL9, HL10, HL11, HL12, HL13, HL14, HL15, HL16, HL17, HL19, HL20, HL21, HL22, HL23, HL24, HL25, HL26, HL27, HL28, HL29, HL30, HL31, HL32, HL33, HL34, HL35, HL36, HL37, HL38, HL39, HL40, HL41, HL42, HL43, HL44, HL45, HL46, HL47, HL48, HL49, HL50, HL51, HL52, HL53, HL54, HL55, HL56, HL57, HL58, HL59, HL60, HL61, HL62, HL63, HL64, HL65, HL66, HL67, HL68, HL69: SLSS49E-3; SLSS49E-3 with MX holes; LCSC C2904393
R10, R11, R12, R13, R14, R15, R16, R17, R18, R19, R20, R21, R22, R23, R24, R25, R26, R27, R29, R30, R31, R32, R33, R34, R35, R37, R38, R39, R40, R41, R42, R43, R44, R45, R46, R47, R48, R49, R52, R53, R54, R55, R56, R57, R58, R59, R60, R61, R62, R63, R64, R66, R67, R68, R69, R70, R71, R72, R73, R74, R75, R76, R77, R78, R79, R80, R81, R82, R83: 10k; R_0805_2012Metric; LCSC C17414

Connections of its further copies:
+3V3: C21.2, C23.2, C25.2, C27.2, C29.2, C31.2, C33.2, C35.2, C37.2, C39.2, C41.2, C43.2, C45.2, C47.2, C49.2, C51.2, C53.2, C55.2, C59.2, C61.2, C63.2, C65.2, C67.2, C69.2, C71.2, C75.2, C77.2, C79.2, C81.2, C83.2, C85.2, C87.2, C89.2, C91.2, C93.2, C95.2, C97.2, C99.2, C105.2, C107.2, C109.2, C111.2, C113.2, C115.2, C117.2, C119.2, C121.2, C123.2, C125.2, C127.2, C129.2, C133.2, C135.2, C137.2, C139.2, C141.2, C143.2, C145.2, C147.2, C149.2, C151.2, C153.2, C155.2, C157.2, C260.2, C263.2, C266.2, C269.2, C272.2, HL0.1 (VDD), HL1.1 (VDD), HL2.1 (VDD), HL3.1 (VDD), HL4.1 (VDD), HL5.1 (VDD), HL6.1 (VDD), HL7.1 (VDD), HL8.1 (VDD), HL9.1 (VDD), HL10.1 (VDD), HL11.1 (VDD), HL12.1 (VDD), HL13.1 (VDD), HL14.1 (VDD), HL15.1 (VDD), HL16.1 (VDD), HL17.1 (VDD), HL19.1 (VDD), HL20.1 (VDD), HL21.1 (VDD), HL22.1 (VDD), HL23.1 (VDD), HL24.1 (VDD), HL25.1 (VDD), HL26.1 (VDD), HL27.1 (VDD), HL28.1 (VDD), HL29.1 (VDD), HL30.1 (VDD), HL31.1 (VDD), HL32.1 (VDD), HL33.1 (VDD), HL34.1 (VDD), HL35.1 (VDD), HL36.1 (VDD), HL37.1 (VDD), HL38.1 (VDD), HL39.1 (VDD), HL40.1 (VDD), HL41.1 (VDD), HL42.1 (VDD), HL43.1 (VDD), HL44.1 (VDD), HL45.1 (VDD), HL46.1 (VDD), HL47.1 (VDD), HL48.1 (VDD), HL49.1 (VDD), HL50.1 (VDD), HL51.1 (VDD), HL52.1 (VDD), HL53.1 (VDD), HL54.1 (VDD), HL55.1 (VDD), HL56.1 (VDD), HL57.1 (VDD), HL58.1 (VDD), HL59.1 (VDD), HL60.1 (VDD), HL61.1 (VDD), HL62.1 (VDD), HL63.1 (VDD), HL64.1 (VDD), HL65.1 (VDD), HL66.1 (VDD), HL67.1 (VDD), HL68.1 (VDD), HL69.1 (VDD); also elsewhere on the board
/multiplexers/keys/KEYS_0_0: C22.1, R10.1; also elsewhere on the board
/multiplexers/keys/KEYS_0_1: C24.1, R11.1; also elsewhere on the board
/multiplexers/keys/KEYS_0_4: C30.1, R14.1; also elsewhere on the board
/multiplexers/keys/KEYS_0_5: C32.1, R15.1; also elsewhere on the board
/multiplexers/keys/KEYS_0_6: C34.1, R16.1; also elsewhere on the board
/multiplexers/keys/KEYS_0_7: C36.1, R17.1; also elsewhere on the board
/multiplexers/keys/KEYS_0_8: C38.1, R18.1; also elsewhere on the board
/multiplexers/keys/KEYS_0_9: C40.1, R19.1; also elsewhere on the board
/multiplexers/keys/KEYS_0_10: C42.1, R20.1; also elsewhere on the board
/multiplexers/keys/KEYS_0_11: C44.1, R21.1; also elsewhere on the board
/multiplexers/keys/KEYS_0_12: C46.1, R22.1; also elsewhere on the board
/multiplexers/keys/KEYS_1_0: C48.1, R23.1; also elsewhere on the board
/multiplexers/keys/KEYS_1_1: C50.1, R24.1; also elsewhere on the board
/multiplexers/keys/KEYS_1_4: C56.1, R27.1; also elsewhere on the board
/multiplexers/keys/KEYS_1_6: C60.1, R29.1; also elsewhere on the board
/multiplexers/keys/KEYS_1_7: C62.1, R30.1; also elsewhere on the board
/multiplexers/keys/KEYS_1_8: C64.1, R31.1; also elsewhere on the board
/multiplexers/keys/KEYS_1_9: C66.1, R32.1; also elsewhere on the board
/multiplexers/keys/KEYS_1_10: C68.1, R33.1; also elsewhere on the board
/multiplexers/keys/KEYS_1_11: C70.1, R34.1; also elsewhere on the board
/multiplexers/keys/KEYS_1_12: C72.1, R35.1; also elsewhere on the board
/multiplexers/keys/KEYS_2_0: C76.1, R37.1; also elsewhere on the board
/multiplexers/keys/KEYS_2_1: C78.1, R38.1; also elsewhere on the board
/multiplexers/keys/KEYS_2_4: C84.1, R41.1; also elsewhere on the board
/multiplexers/keys/KEYS_2_5: C86.1, R42.1; also elsewhere on the board
/multiplexers/keys/KEYS_2_6: C88.1, R43.1; also elsewhere on the board
/multiplexers/keys/KEYS_2_7: C90.1, R44.1; also elsewhere on the board
/multiplexers/keys/KEYS_2_8: C92.1, R45.1; also elsewhere on the board
/multiplexers/keys/KEYS_2_9: C94.1, R46.1; also elsewhere on the board
/multiplexers/keys/KEYS_2_10: C96.1, R47.1; also elsewhere on the board
/multiplexers/keys/KEYS_2_11: C98.1, R48.1; also elsewhere on the board
/multiplexers/keys/KEYS_2_12: C100.1, R49.1; also elsewhere on the board
/multiplexers/keys/KEYS_2_13: C273.1, R83.1; also elsewhere on the board
/multiplexers/keys/KEYS_3_0: C106.1, R52.1; also elsewhere on the board
/multiplexers/keys/KEYS_3_1: C108.1, R53.1; also elsewhere on the board
/multiplexers/keys/KEYS_3_2: C110.1, R54.1; also elsewhere on the board
/multiplexers/keys/KEYS_3_3: C112.1, R55.1; also elsewhere on the board
/multiplexers/keys/KEYS_3_4: C114.1, R56.1; also elsewhere on the board
/multiplexers/keys/KEYS_3_5: C116.1, R57.1; also elsewhere on the board
/multiplexers/keys/KEYS_3_6: C118.1, R58.1; also elsewhere on the board
/multiplexers/keys/KEYS_3_7: C120.1, R59.1; also elsewhere on the board
/multiplexers/keys/KEYS_3_8: C122.1, R60.1; also elsewhere on the board
/multiplexers/keys/KEYS_3_9: C124.1, R61.1; also elsewhere on the board
/multiplexers/keys/KEYS_3_10: C126.1, R62.1; also elsewhere on the board
/multiplexers/keys/KEYS_3_11: C128.1, R63.1; also elsewhere on the board
/multiplexers/keys/KEYS_3_12: C130.1, R64.1; also elsewhere on the board
/multiplexers/keys/KEYS_3_13: C261.1, R80.1; also elsewhere on the board
/multiplexers/keys/KEYS_3_14: C264.1, R79.1; also elsewhere on the board
/multiplexers/keys/KEYS_4_0: C134.1, R66.1; also elsewhere on the board
/multiplexers/keys/KEYS_4_1: C136.1, R67.1; also elsewhere on the board
/multiplexers/keys/KEYS_4_2: C138.1, R68.1; also elsewhere on the board
/multiplexers/keys/KEYS_4_3: C140.1, R69.1; also elsewhere on the board
/multiplexers/keys/KEYS_4_4: C142.1, R70.1; also elsewhere on the board
/multiplexers/keys/KEYS_4_5: C144.1, R71.1; also elsewhere on the board
/multiplexers/keys/KEYS_4_6: C146.1, R72.1; also elsewhere on the board
/multiplexers/keys/KEYS_4_7: C148.1, R73.1; also elsewhere on the board
/multiplexers/keys/KEYS_4_8: C150.1, R74.1; also elsewhere on the board
/multiplexers/keys/KEYS_4_9: C152.1, R75.1; also elsewhere on the board
/multiplexers/keys/KEYS_4_10: C154.1, R76.1; also elsewhere on the board
/multiplexers/keys/KEYS_4_11: C156.1, R77.1; also elsewhere on the board
/multiplexers/keys/KEYS_4_12: C158.1, R78.1; also elsewhere on the board
/multiplexers/keys/KEYS_4_13: C267.1, R81.1; also elsewhere on the board
/multiplexers/keys/KEYS_4_14: C270.1, R82.1; also elsewhere on the board
unnamed: HL0.3 (VOUT), R10.2
unnamed: HL1.3 (VOUT), R11.2
unnamed: HL2.3 (VOUT), R12.2
unnamed: HL3.3 (VOUT), R13.2
unnamed: HL4.3 (VOUT), R14.2
unnamed: HL5.3 (VOUT), R15.2
unnamed: HL6.3 (VOUT), R16.2
unnamed: HL7.3 (VOUT), R17.2
unnamed: HL8.3 (VOUT), R18.2
unnamed: HL9.3 (VOUT), R19.2
unnamed: HL10.3 (VOUT), R20.2
unnamed: HL11.3 (VOUT), R21.2
unnamed: HL12.3 (VOUT), R22.2
unnamed: HL13.3 (VOUT), R23.2
unnamed: HL14.3 (VOUT), R24.2
unnamed: HL15.3 (VOUT), R25.2
unnamed: HL16.3 (VOUT), R26.2
unnamed: HL17.3 (VOUT), R27.2
unnamed: HL19.3 (VOUT), R29.2
unnamed: HL20.3 (VOUT), R30.2
unnamed: HL21.3 (VOUT), R31.2
unnamed: HL22.3 (VOUT), R32.2
unnamed: HL23.3 (VOUT), R33.2
unnamed: HL24.3 (VOUT), R34.2
unnamed: HL25.3 (VOUT), R35.2
unnamed: HL26.3 (VOUT), R37.2
unnamed: HL27.3 (VOUT), R38.2
unnamed: HL28.3 (VOUT), R39.2
unnamed: HL29.3 (VOUT), R40.2
unnamed: HL30.3 (VOUT), R41.2
unnamed: HL31.3 (VOUT), R42.2
unnamed: HL32.3 (VOUT), R43.2
unnamed: HL33.3 (VOUT), R44.2
unnamed: HL34.3 (VOUT), R45.2
unnamed: HL35.3 (VOUT), R46.2
unnamed: HL36.3 (VOUT), R47.2
unnamed: HL37.3 (VOUT), R48.2
unnamed: HL38.3 (VOUT), R49.2
unnamed: HL39.3 (VOUT), R83.2
unnamed: HL40.3 (VOUT), R52.2
unnamed: HL41.3 (VOUT), R53.2
unnamed: HL42.3 (VOUT), R54.2
unnamed: HL43.3 (VOUT), R55.2
unnamed: HL44.3 (VOUT), R56.2
unnamed: HL45.3 (VOUT), R57.2
unnamed: HL46.3 (VOUT), R58.2
unnamed: HL47.3 (VOUT), R59.2
unnamed: HL48.3 (VOUT), R60.2
unnamed: HL49.3 (VOUT), R61.2
unnamed: HL50.3 (VOUT), R62.2
unnamed: HL51.3 (VOUT), R63.2
unnamed: HL52.3 (VOUT), R64.2
unnamed: HL53.3 (VOUT), R80.2
unnamed: HL54.3 (VOUT), R79.2
unnamed: HL55.3 (VOUT), R66.2
unnamed: HL56.3 (VOUT), R67.2
unnamed: HL57.3 (VOUT), R68.2
unnamed: HL58.3 (VOUT), R69.2
unnamed: HL59.3 (VOUT), R70.2
unnamed: HL60.3 (VOUT), R71.2
unnamed: HL61.3 (VOUT), R72.2
unnamed: HL62.3 (VOUT), R73.2
unnamed: HL63.3 (VOUT), R74.2
unnamed: HL64.3 (VOUT), R75.2
unnamed: HL65.3 (VOUT), R76.2
unnamed: HL66.3 (VOUT), R77.2
unnamed: HL67.3 (VOUT), R78.2
unnamed: HL68.3 (VOUT), R81.2
unnamed: HL69.3 (VOUT), R82.2

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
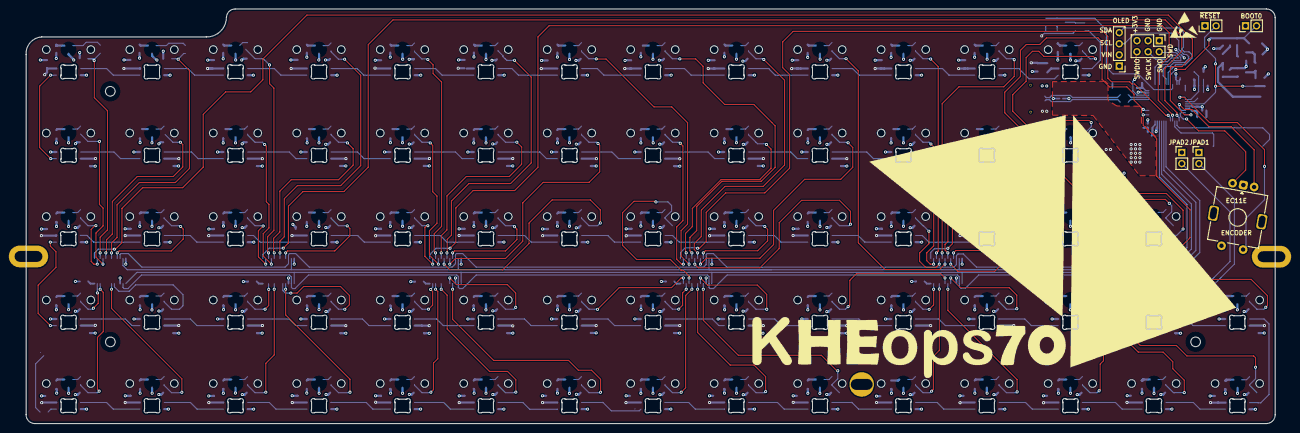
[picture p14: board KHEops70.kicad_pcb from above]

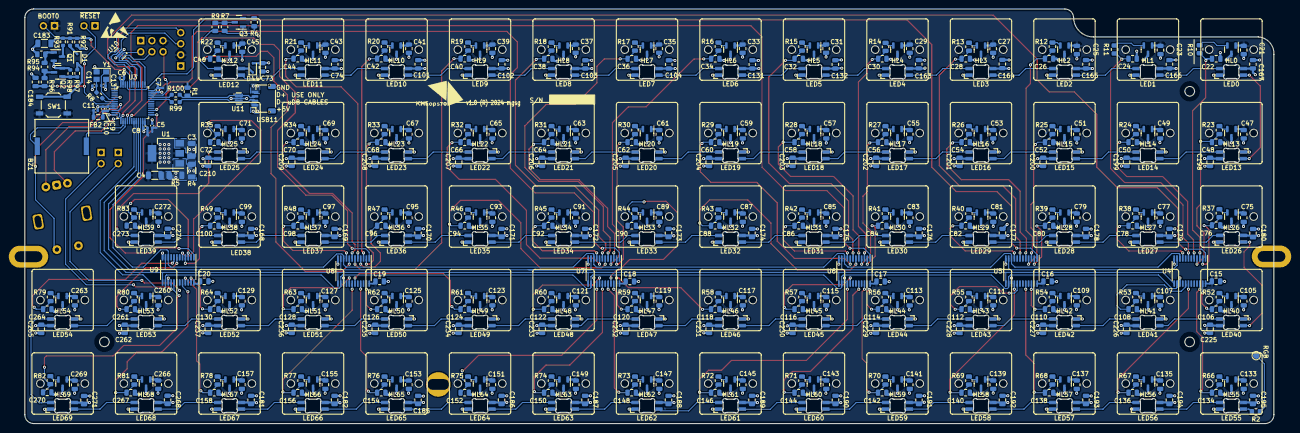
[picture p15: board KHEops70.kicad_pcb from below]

Board: 4 copper layers, 285.0 x 94.6 mm, 495 parts (480 on the bottom side), 258 nets.

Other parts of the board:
REF-Antistatic-Logo-Back: ESD-Logo_6.6x6mm_SilkScreen
REF-Antistatic-Logo-Front: ESD-Logo_6.6x6mm_SilkScreen
REF-KHEops70-logo-back: LOGO; KHEops70-logo-m
